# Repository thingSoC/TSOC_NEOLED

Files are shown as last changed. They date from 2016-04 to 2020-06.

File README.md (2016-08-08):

# TSOC_NEOLED

**TSOC_NEOLED** is a Eight-Channel WS2812 LED driver expansion board, and can drive
eight (8) to sixteen(16) strips of individually addressable Light Emitting Diodes (LEDs). 

**TSOC_NEOLED** uses a programmable system on chip (PSoC4) with an eight (8) channel driver
to drive hundreds of WS2812 Color LED's, with a default arrangement of 8 (eight strings) of sixty-four(64) LEDs each.

The **TSOC_NEOLED** can provide several different intefaces in order to make
interfacing large numbers of LEDs easy. The default protocol is an I2C interface :

1) I2C Serial DMX-512, Memory Mapped (**TSOC_NEOLED** looks like a 2048 byte I2C SRAM)

Other Interface protocols are possible (Firmware update using FTDI/USB-UART or JTAG) :

- UART Serial DMX-512 (200K Baud, N, 8, 1) with four DMX universes.

- SPI Serial DMX-512, Memory Mapped (**TSOC_NEOLED** looks like a 2048 byte SPI SRAM)

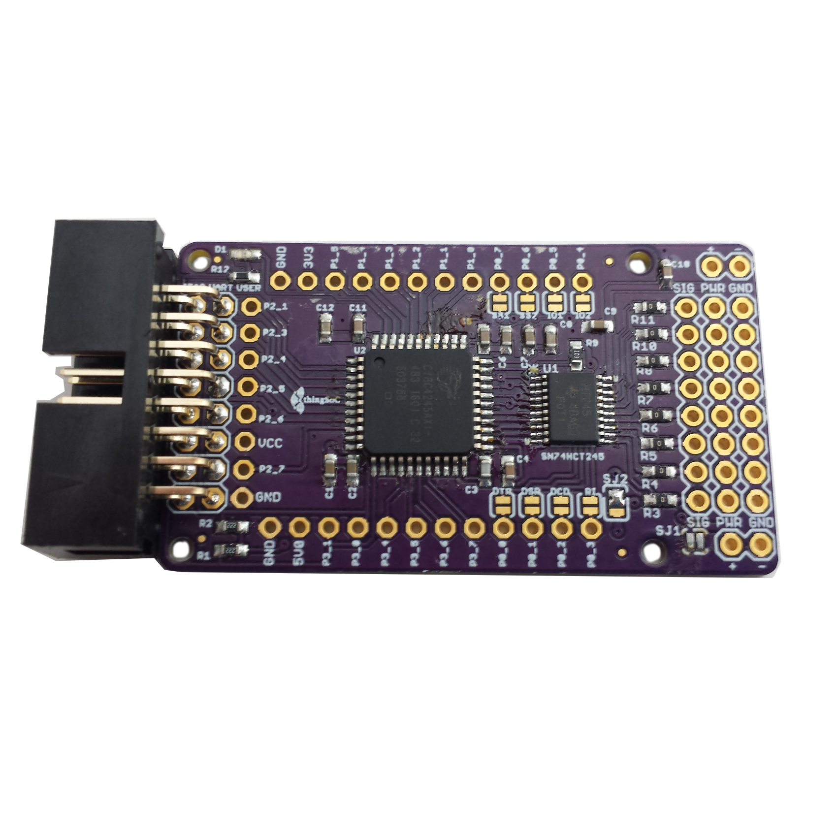
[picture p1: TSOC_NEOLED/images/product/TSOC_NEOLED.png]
thingSoC TSOC_NEOLED
[TSOC_NEOLED](https://github.com/thingSoC/TSOC_NEOLED)

**thingSoC Reference Designs** are example thingSoC implementations that implement
various reference and testing circuits for demonstrating the use of the thingSoC libraries.
These reference designs can serve as starting templates for user designs.

---------------------------------------

## TSOC_NEOLED Application Pictures

Using the TSOC_NEOLED to drive eight(8) strings of color LEDs for lighting our tandem bike for Portland PedalPolooza 2016

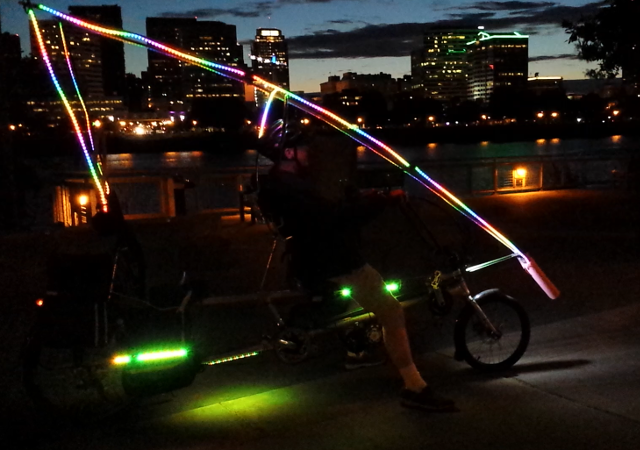
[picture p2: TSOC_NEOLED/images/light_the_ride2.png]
thingSoC TSOC_NEOLED
[*TSOC_NEOLED*](https://github.com/thingSoC/TSOC_NEOLED)

---------------------------------------

## TSOC_NEOLED Arduino Sketch Examples

Under the "examples" directory are several Arduino IDE examples for using the TSOC_NEOLED board with Arduino IDE.
Using the Arduino "Wire" library for I2C communications, it is simple to control the TSOC_NEOLED

```c
  // Start the Arduino I2C Interface
  wire.begin();

  // Turn the first LED On (i.e. green LED #1) 
  // the LED's are (GRBY) color order in memory
  byte row, column = 0;
  Wire.beginTransmission(TSOC_NEOLED_I2CADDRESS);  // Start the I2C transaction
  Wire.write(row);                                 // Send the high byte of 16 bit memory address
  Wire.write(column);                              // Send the low byte of 16 bit memory address
  Wire.write(TSOC_NEOLED_LED_ON);                  // Send a single data byte  (we could send more...)
  Wire.endTransmission();                          // End the I2C transaction
 
  // Turn the first LED Off (i.e. green LED #1) 
  // the LED's are (GRBY) color order in memory
  Wire.beginTransmission(TSOC_NEOLED_I2CADDRESS);  // Start the I2C transaction
  Wire.write(row);                                 // Send the high byte of 16 bit memory address
  Wire.write(column);                              // Send the low byte of 16 bit memory address
  Wire.write(TSOC_NEOLED_LED_OFF);                  // Send a single data byte  (we could send more...)
  Wire.endTransmission();                          // End the I2C transaction

```

---------------------------------------
## TSOC_NEOLED Programming

You can reprogram the board using any FTDI compatible USB to UART adapter :

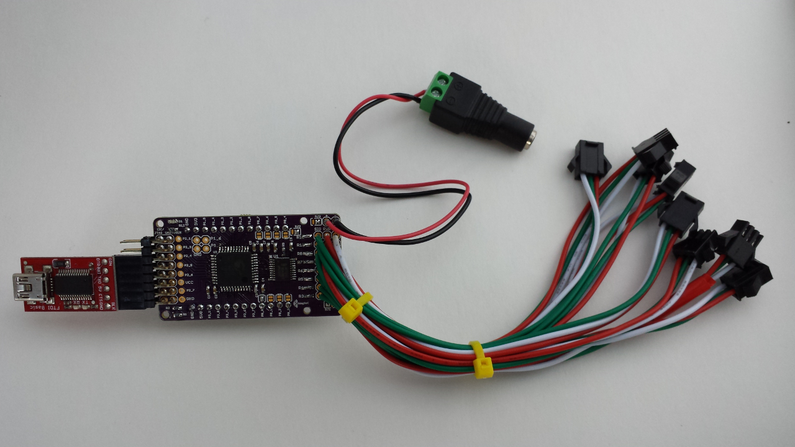
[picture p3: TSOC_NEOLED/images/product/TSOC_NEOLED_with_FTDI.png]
thingSoC TSOC_NEOLED
[TSOC_NEOLED with FTDI basic](https://github.com/thingSoC/TSOC_NEOLED)

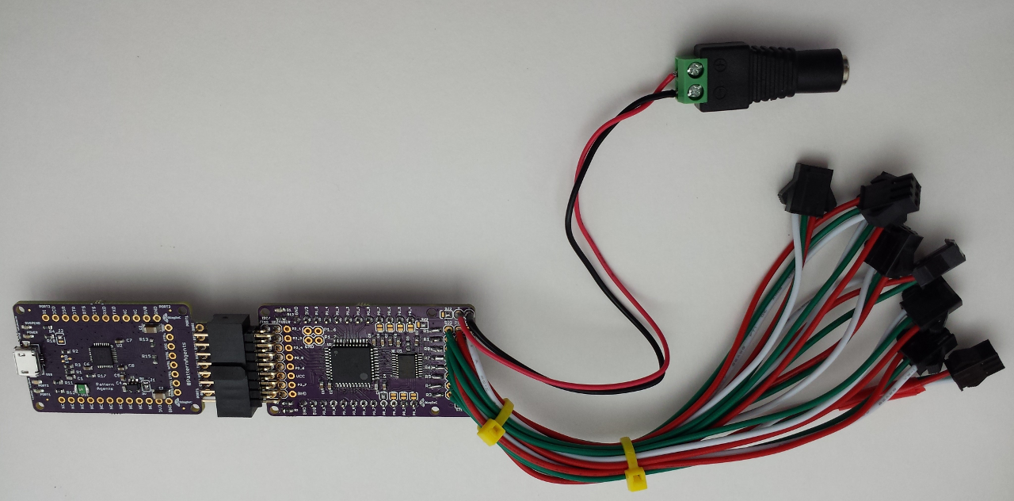
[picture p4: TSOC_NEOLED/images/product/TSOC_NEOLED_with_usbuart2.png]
thingSoC TSOC_NEOLED
[TSOC_NEOLED with TSOC_USBUART2](https://github.com/thingSoC/TSOC_NEOLED)

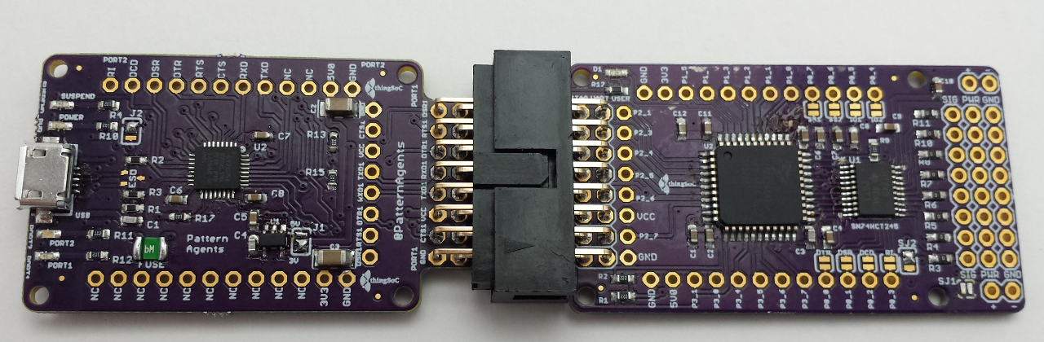
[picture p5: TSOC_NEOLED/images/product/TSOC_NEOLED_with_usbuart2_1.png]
thingSoC TSOC_NEOLED
[TSOC_NEOLED with TSOC_USBUART2](https://github.com/thingSoC/TSOC_NEOLED)

In order to reprogram the Cypress PSoC4 device, you will need to download and install the PSoC Creator tool, which includes a serial bootloader host application.

Select Tools -> Bootloader Host 

Then select the hex (cyacd) file that you wish to program, and the COM: port of your device. Proess the "Upload" button to reflash teh device.

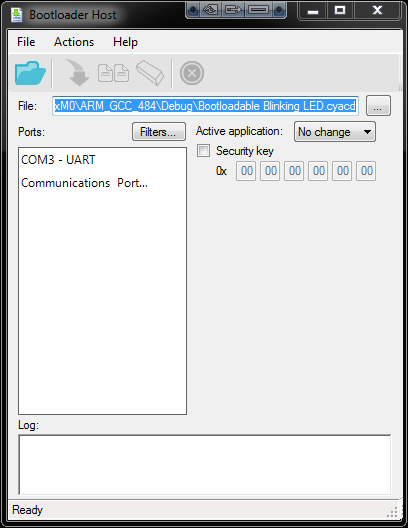
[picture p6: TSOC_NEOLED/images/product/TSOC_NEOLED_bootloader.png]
thingSoC TSOC_NEOLED
[PSoC Creator Bootloader Host](https://github.com/thingSoC/TSOC_NEOLED)

---------------------------------------
## Other Applications

The TSOC_NEOLED can also drive other devices, such as Servos, Motors, Realys and more.
This requires custom firmware at the current time.

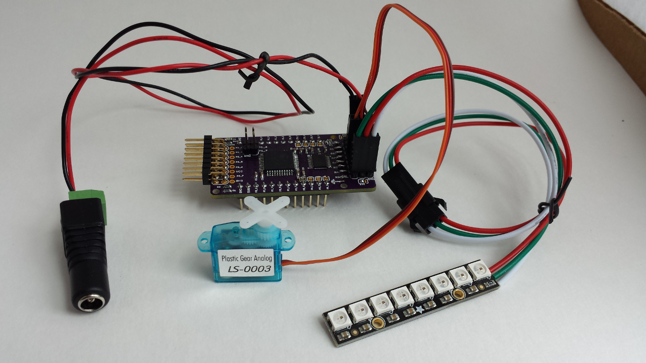
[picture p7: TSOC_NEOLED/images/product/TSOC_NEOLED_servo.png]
thingSoC TSOC_NEOLED
[TSOC_NEOLED with Servo](https://github.com/thingSoC/TSOC_NEOLED)

---------------------------------------

## TSOC_NEOLED Status <a name="TSOC_NEOLED_status"/>

**04/28/2016:** 
Revision 1.1 - Initial Layout with Eight(8) channel driver.

**06/27/2016:**
Revision 1.2 - Added extra power connections for higher current support.

**07/26/2016:**
Revision 2.0 -

               Moved extra jumpers to the Digital Programming Connector (i.e. boot-mode control).

               Added SAR Bypass capactitors in their place.  
               
               Misc Silkscreen clean up.  
               
               Add Fiducials and DFM cleanup.

---------------------------------------
## TSOC_NEOLED Model Images

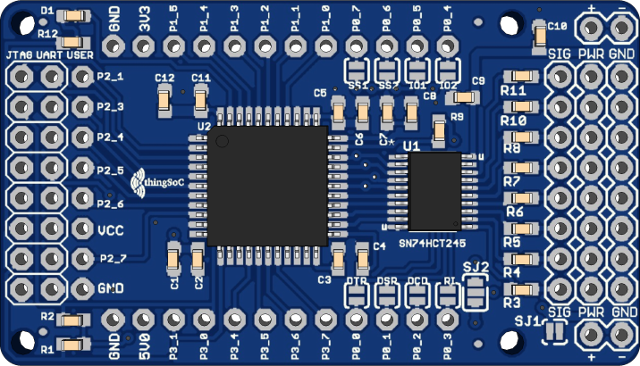
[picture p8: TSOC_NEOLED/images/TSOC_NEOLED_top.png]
thingSoC TSOC_NEOLED
[TSOC_NEOLED](https://github.com/thingSoC/TSOC_NEOLED)

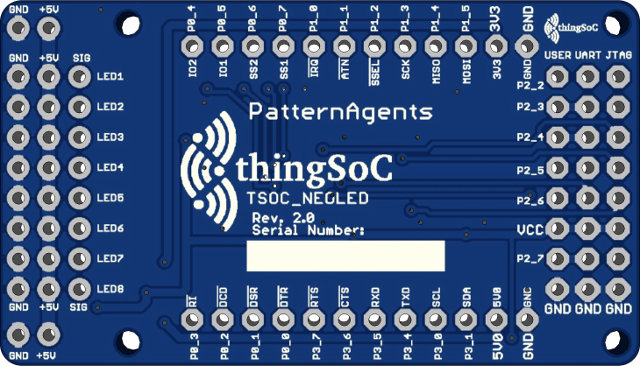
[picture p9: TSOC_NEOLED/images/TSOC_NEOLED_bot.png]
thingSoC TSOC_NEOLED
[TSOC_NEOLED](https://github.com/thingSoC/TSOC_NEOLED)

---------------------------------------

## TSOC_NEOLED Documentation Index <a name="TSOC_NEOLED_documentation_index"/>

[TSOC_NEOLED Project](http://thingsoc.github.io/projects/TSOC_NEOLED.html)

[TSOC_NEOLED Hardware](https://github.com/thingSoC/TSOC_NEOLED/tree/master/TSOC_NEOLED/hardware)

---------------------------------------

## thingSoC Documentation Index <a name="thingSoC_documentation_index"/>

[thingSoC Organization Website](http://thingSoC.github.io)

[thingSoC FAQ - Frequently Asked Questions](http://thingsoc.github.io/support/faq.html)

---------------------------------------

[thingSoC 
*thingSoC*](http://thingsoc.github.io)

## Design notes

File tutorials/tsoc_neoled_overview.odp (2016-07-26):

## thingSoC

  NEOLED Overview:  An Introduction to WS2812 LEDs

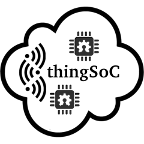
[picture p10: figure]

By
@PatternAgents

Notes: Hey Everybody! I’m Tom Moxon, and I’m very pleased to be speaking with you today- I see some new faces in the audience as well as some old friends – welcome !

## Addressable LEDs

- WS2810/WS2812 (a.k.a. NEOPixels by Adafruit) Integrates an LED driver chip with Red, Green, Blue LED's

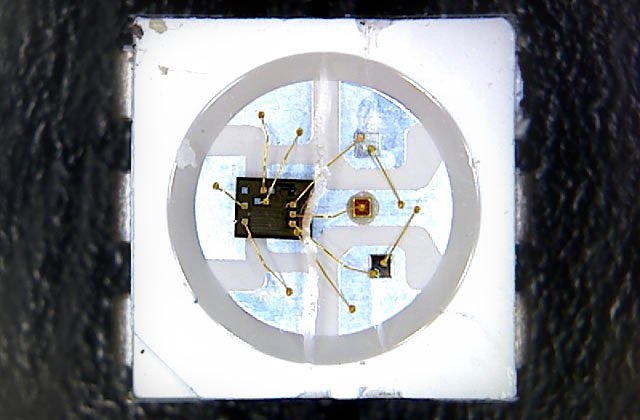
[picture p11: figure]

## WS2812 (SK6812) Color LEDs

- Likely the most common addressable LED you'll find (called NEOPixels when you buy them at Adafruit!)
- They use a serial bit stream (UART like) protocol that can be difficult for some microcontrollers or Linux single board computers (SBC) to drive directly (tight timing...)
- It can also be difficult to drive and synchronize hundreds of WS2812 LEDs in multiple strings without hardware acceleration of some kind (special circuit, DMA, etc.)
  Source : @PatternAgents

## WS2812 Wiring

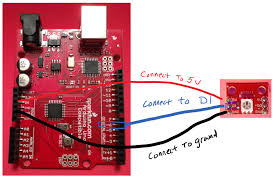
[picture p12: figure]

- Needs 5.0 Volt Power
- Needs 5.0 Volt Signal
- Can draw AMPS of Power with many LEDs
- Do NOT do this with more than a few LEDs, it can fry your Arduino boards...

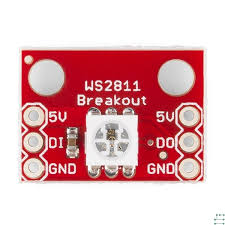
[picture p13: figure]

  Source : Sparkfun

## WS2812 Wiring

- Best Practice is to power the LED strings separately:

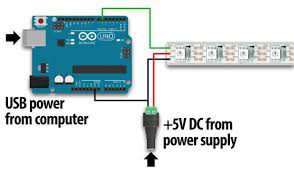
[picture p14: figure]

## WS2812 Timing

- The older WS2810 was a 400KHz serial data signal
- The newer WS2811/WS2812 are now 800KHz data signals

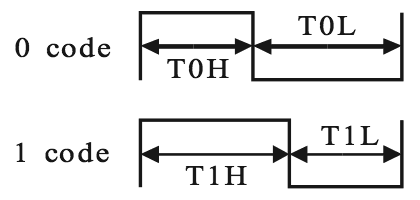
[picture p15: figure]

  Source : Adafruit

## WS2812 LED Color Order

- Eight (8) bits each for Green, Red, Blue
- Different chips can use different color orders (beware!)
- Some add White or Yellow LEDs for a 32 bit color pixel
  Source : Adafruit

## Arduino Libraries

- Adafruit NeoPixel Library : Well written, supports AVR, ESP8266, SAMD, etc.
- FastLeds Library : Optimized, with higher performance and update rates
- Problems : 1) Can interfere with other functions, like audio, servos, etc. 2) Can use up a lot of the “scarce” memory resource 3) Doesn't work well with the Edison, Currie, Galileo, etc.
  Source : Adafruit

## thingSoC is a OSHW Standard

Growing into a family of inter-operable products:

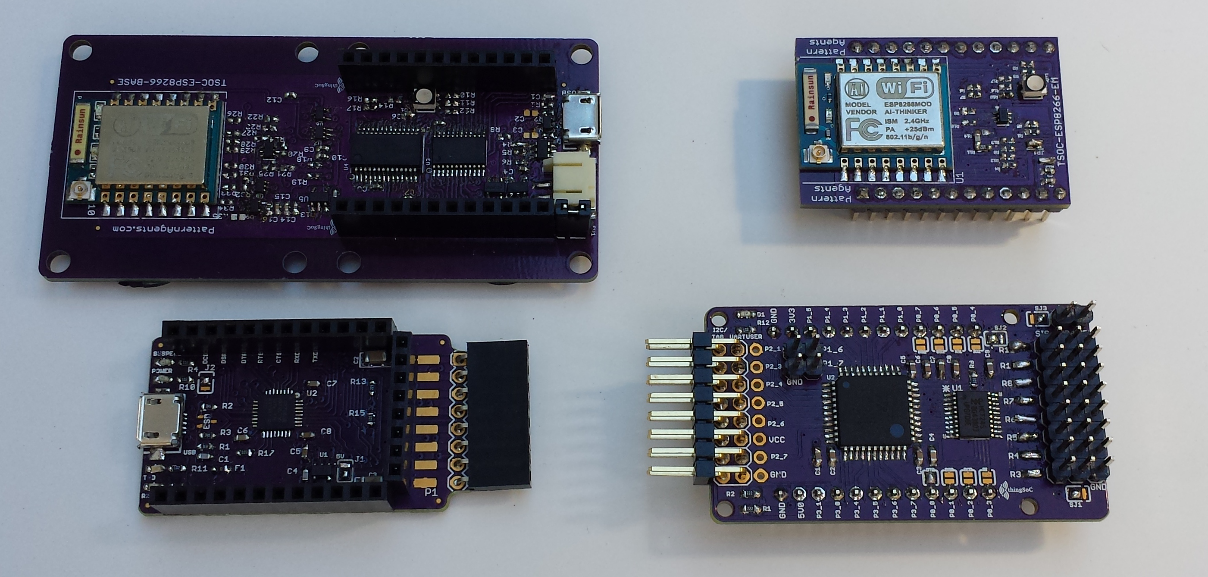
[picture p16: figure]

  source: @PatternAgents

## TSOC_NEOLED_EM

- Eight (8) Channel RBG(Y) LED Driver Board (Embeddable Module) Makes driving LED arrays as easy as writing to an I2C memory
- Reprogrammable for other functions (servo motors, etc.)
- Works with other thingSoC products
- Coming soon to Crowd Supply here in Portland!

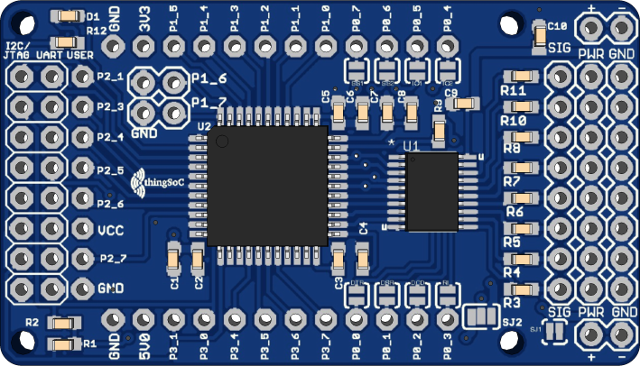
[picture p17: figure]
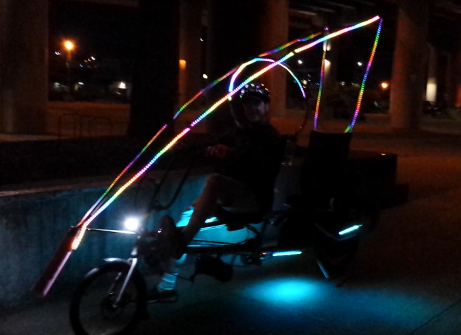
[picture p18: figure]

  Source : @PatternAgents

## Driving WS2812 with Edison

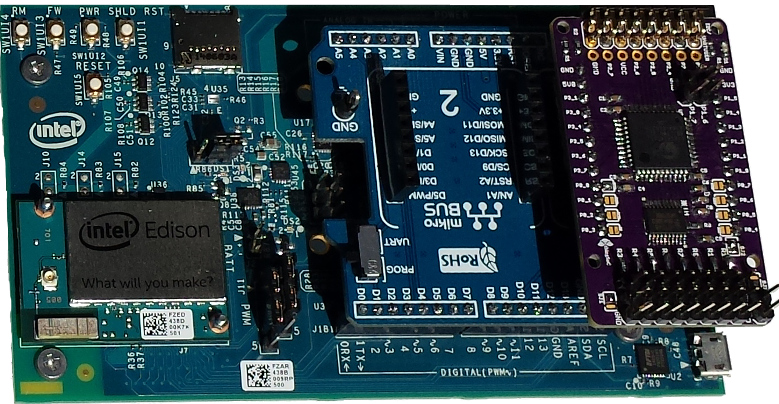
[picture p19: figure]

  source: @PatternAgents

## Driving WS2812 with Edison

- While there are ways to drive WS2812 LEDs directly from the Edison (MRAA), they are not easy and have other problems.
- Using the TSOC_NEOLED board eliminates the timing and voltage level translation issues for you.
- The TSOC_NEOLED board looks like a simple I2C memory device to the Edison, simplifying your code.

Driving WS2812 with Edison

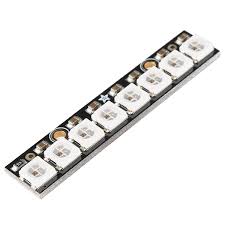
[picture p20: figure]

  source: @PatternAgents

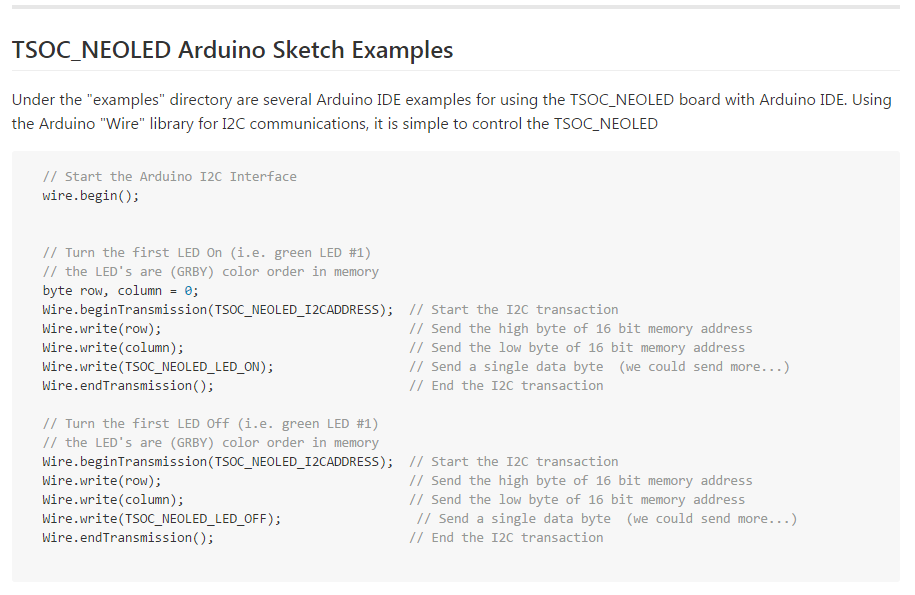
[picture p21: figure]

  source: @PatternAgents

## Hackster.io Platform

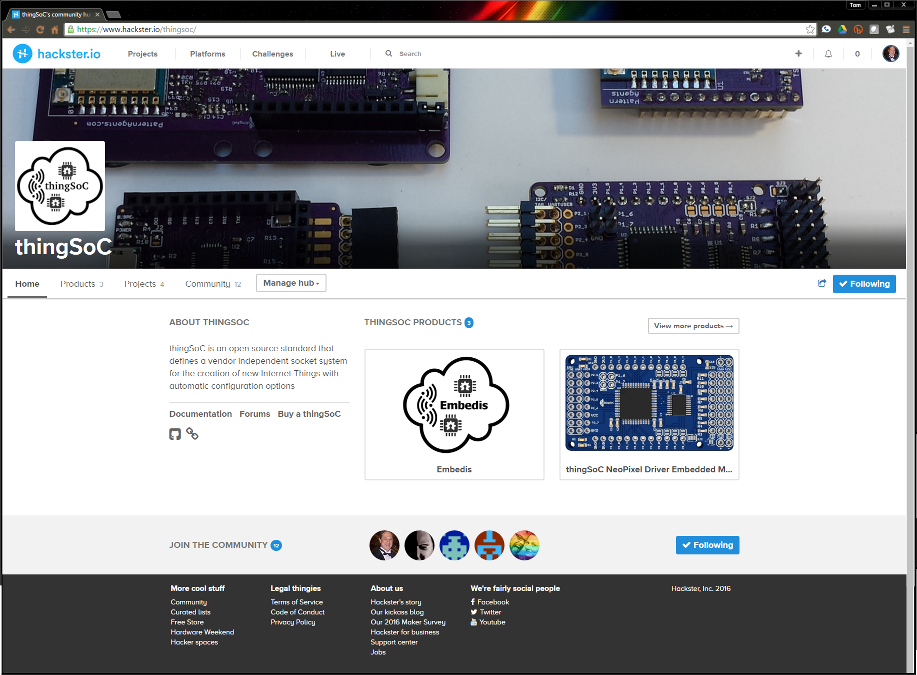
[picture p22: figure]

  source: PatternAgents

## Hackster.io Projects

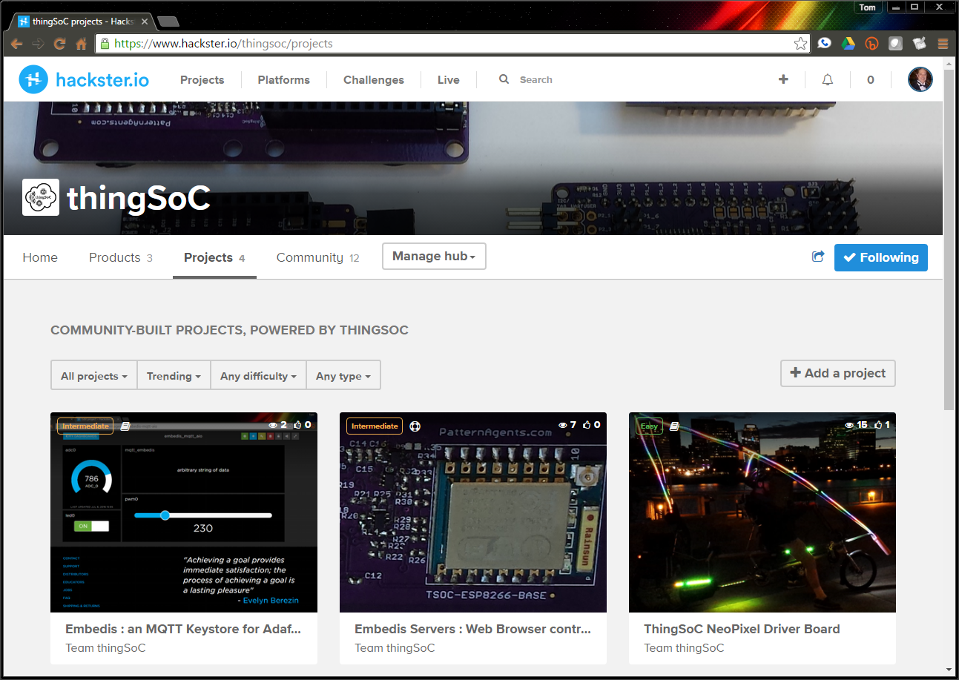
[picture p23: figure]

  source: PatternAgents

## If you would like to help...

- Sign Up for Hackster.IO
- Please go to : https://www.hackster.io/thingsoc and “Click” on the blue “Following” button
- Look for our Crowd Supply campaign coming soon!

## Thank You !

  Thank You!
  Source : @PatternAgents

## @Pattern Agents

- PatternAgents supplies Open Source Design Patterns for Hardware, Firmware, Software, and Applications.
- A tailor or dressmaker is very familiar with the concept of a "pattern"; they select a “pattern” for the style of garment that they want to make, and then size that “pattern” for the customers individual measurements.
- PatternAgents is doing the same thing for electronics, in embedded systems for communications, robotics, metering and automation.

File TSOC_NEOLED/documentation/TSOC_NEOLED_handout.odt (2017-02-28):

thingSoC NEOLED Board

Thank you for purchasing a TSOC_NEOLED board!
Please see the Getting Started Guide at :
https://github.com/thingSoC/TSOC_NEOLED
It has complete instructions and examples to download.

thingSoC NEOLED Board

Thank you for purchasing a TSOC_NEOLED board!
Please see the Getting Started Guide at :
https://github.com/thingSoC/TSOC_NEOLED
It has complete instructions and examples to download.

thingSoC NEOLED Board

Thank you for purchasing a TSOC_NEOLED board!
Please see the Getting Started Guide at :
https://github.com/thingSoC/TSOC_NEOLED
It has complete instructions and examples to download.

thingSoC NEOLED Board

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

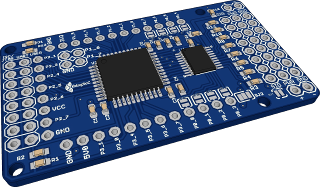
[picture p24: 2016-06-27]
TSOC_NEOLED/images/rev2.0/TSOC_NEOLED_model.png

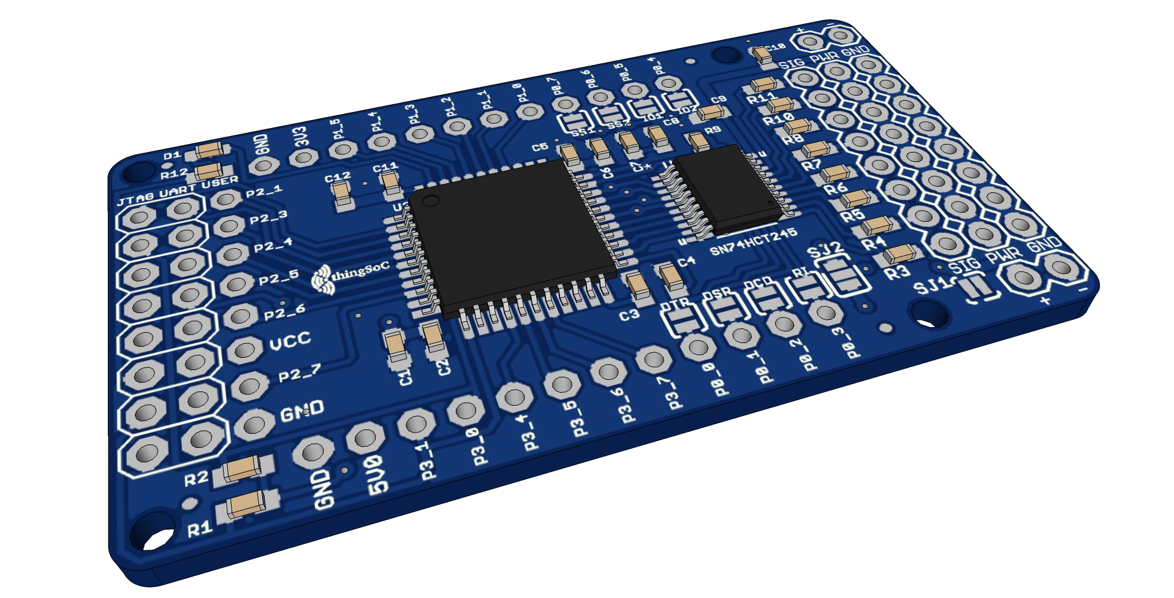
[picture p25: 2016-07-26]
TSOC_NEOLED/images/rev2.0/TSOC_NEOLED_iso.png

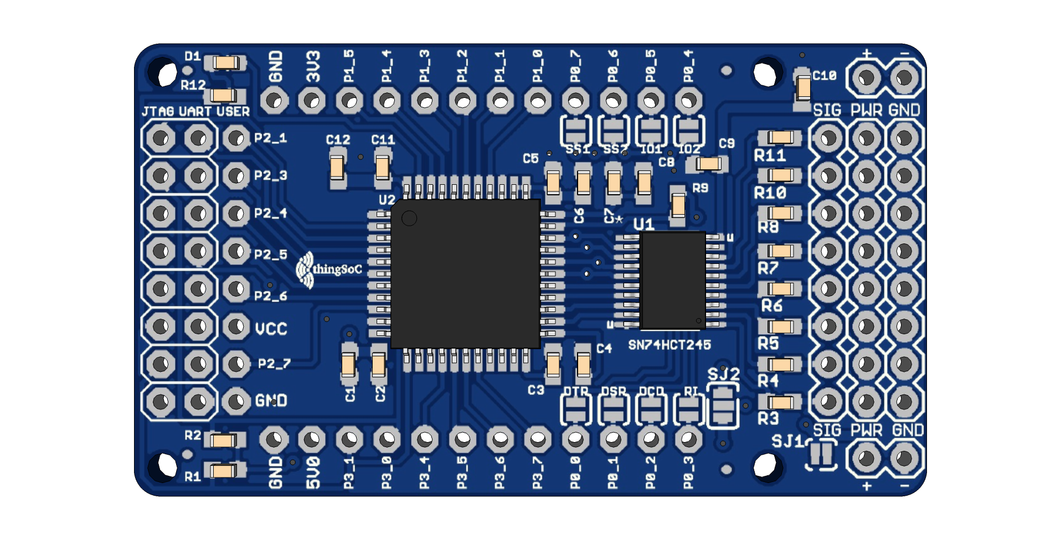
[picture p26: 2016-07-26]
TSOC_NEOLED/images/rev2.0/TSOC_NEOLED_top.png

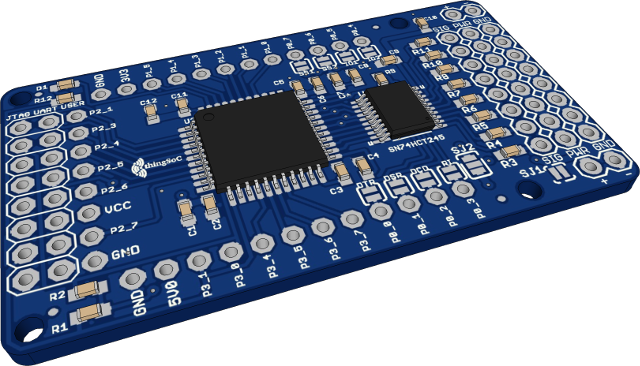
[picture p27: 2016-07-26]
TSOC_NEOLED/images/TSOC_NEOLED_iso.png

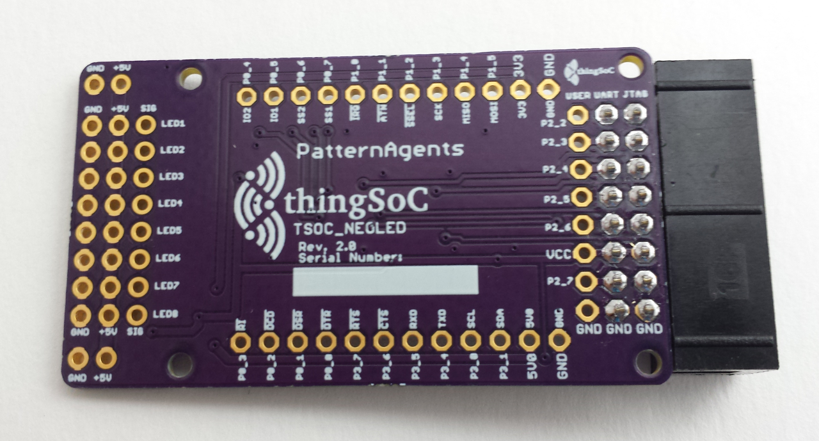
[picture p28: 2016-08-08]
TSOC_NEOLED/images/product/TSOC_NEOLED_bot.png

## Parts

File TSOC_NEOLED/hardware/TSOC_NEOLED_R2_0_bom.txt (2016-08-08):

Partlist exported from U:/PatternAgents/eagle/TSOC_Modules/TSOC_NEOLED/TSOC_NEOLED/TSOC_NEOLED.sch at 7/26/2016 10:40:16 PM
Revison 2.0
------------
Part  Value           Device               Package           Description                      DIGIKEY               MPN 
C1    0.1uF           CAP0603-CAP          0603-CAP          Capacitor                     490-1524-2-ND          muRata GRM188R71E104KA01D  
C2    1uF             CAP0603-CAP          0603-CAP          Capacitor                                            muRata GRM185R61C105K                                                                        
C3    2.2nF           CAP0603-CAP          0603-CAP          Capacitor                                            muRata GRM188R61C225K                                                                        
C4    10nF            CAP0603-CAP          0603-CAP          Capacitor                     490-4778-1-ND          muRata GCM188R71H103KA37D                                                                                          
C5    0.1uF           CAP0603-CAP          0603-CAP          Capacitor                                                                                                                          
C6    1uF             CAP0603-CAP          0603-CAP          Capacitor                                                                                                                          
C7    0.1uF           CAP0603-CAP          0603-CAP          Capacitor                                                                                                                          
C8    1uF             CAP0603-CAP          0603-CAP          Capacitor                                                                                                                          
C9    0.1uF           CAP0603-CAP          0603-CAP          Capacitor                                                                                                                          
C10   0.1uF           CAP0603-CAP          0603-CAP          Capacitor                                                                                                                          
C11   0.1uF           CAP0603-CAP          0603-CAP          Capacitor                                                                                                                          
C12   1uF             CAP0603-CAP          0603-CAP          Capacitor                                                                                                                          
D1    RED             LED0603              LED-0603          LEDs                             475-2506-1-ND        OSRAM   LS L29K-G1J2-1-Z                                                                                          
J1    M08X02          M08X2                2X8               .1" headers, Male, Shrouded, RA  ED10535-ND           On-Shore-Technology-Inc. 302-R161                                                                                            
J2    M08             M08                  1X08              .1" headers, Male, Unshrouded,   S1012EC-08-ND        Sullins  PREC008SAAN-RC                                                                                                                       
J3    M08             M08                  1X08              .1" headers, Male, Unshrouded,   S1012EC-08-ND        Sullins  PREC008SAAN-RC                                                                                                                        
J4    M08             M08                  1X08              .1" headers, Male, Unshrouded,   S1012EC-08-ND        Sullins  PREC008SAAN-RC
J5    M02             M02                  1X02              .1" headers, Male, Unshrouded                                                                                      
J6    M02             M02                  1X02              .1" headers, Male, Unshrouded                                                                           
R1    2K2             RESISTOR0603-RES     0603-RES          Resistor                         RMCF0603JT2K20TR-ND   Stackpole RMCF0603JT2K20                                                                                                  
R2    2K2             RESISTOR0603-RES     0603-RES          Resistor                                                                                                                           
R3    0               RESISTOR0603-RES     0603-RES          Resistor                                                                                                                           
R4    0               RESISTOR0603-RES     0603-RES          Resistor                                                                                                                           
R5    0               RESISTOR0603-RES     0603-RES          Resistor                                                                                                                           
R6    0               RESISTOR0603-RES     0603-RES          Resistor                                                                                                                           
R7    0               RESISTOR0603-RES     0603-RES          Resistor                                                                                                                           
R8    0               RESISTOR0603-RES     0603-RES          Resistor                                                                                                                        
R9    10K             RESISTOR0603-RES     0603-RES          Resistor                         RMCF0603JT10K0TR-ND   Stackpole RMCF0603JT10K0                                                                                           
R10   0               RESISTOR0603-RES     0603-RES          Resistor                                                                                                                           
R11   0               RESISTOR0603-RES     0603-RES          Resistor                                                                                                                           
R12   1K              RESISTOR0603-RES     0603-RES          Resistor                         RMCF0603JT1K00TR-ND   Stackpole RMCF0603JT1K00                                                                                                                                                             
TSOC1 M12             M12                  1X12F             .1" headers, Female              S6100-ND               PPTC121LFBN-RC
TSOC2 M12             M12                  1X12F             .1" headers, Female              S6100-ND               PPTC121LFBN-RC
TSOC3 M08             M08                  1X08F             .1" headers, Female              S7006-ND               PPTC081LFBN-RC                                                                                               
U1    SN74HCT245PWR    SN74HCT245PWR       SOP65P640X120-20N OCTAL BUS TRANS                  296-8404-1-ND          SN74HCT245PWR
U2    CY8C42XX-44PIN  CY8C42XX-44PIN       TQFP-10X10-44     Cypress PSoC® 4                  CY8C4245AXI-483

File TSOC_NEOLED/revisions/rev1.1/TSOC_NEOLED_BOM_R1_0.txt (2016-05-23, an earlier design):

Partlist exported from /home/moxon/github/TSOC_NEOLED/TSOC_NEOLED/TSOC_NEOLED.sch at 4/29/16 10:46 AM
Qty Value           Device               Package           Parts                                 Description                                                     
8                   JMP-2-NO             JMP-2-NO          DCD, DSR, DTR, IO1, IO2, RI, SS1, SS2 Two Terminal Jumper - Normally Open 
1                   LED0603              LED-0603          D1                                    LEDs                                                            
3                   M08                  1X08_ROUND        J2, J3, J4                            Header 8                                                        
1                   M08X2                2X8               J1                                    .1" headers, two rows of 8 each                                 
8                   RESISTOR0603-RES     0603-RES          R3, R4, R5, R6, R7, R8, R10, R11      Resistor                                                        
4   0.1uF           CAP0603-CAP          0603-CAP          C1, C5, C7, C9                        Capacitor                                                       
1   10K             RESISTOR_SFE0603-RES 0603-RES          R9                                    Resistor                                                        
1   10nF            CAP0603-CAP          0603-CAP          C4                                    Capacitor                                                       
1   1K              RESISTOR_SFE0603-RES 0603-RES          R12                                   Resistor                                                        
3   1uF             CAP0603-CAP          0603-CAP          C2, C6, C8                            Capacitor                                                       
1   2.2nF           CAP0603-CAP          0603-CAP          C3                                    Capacitor                                                       
2   2K2             RESISTOR_SFE0603-RES 0603-RES          R1, R2                                Resistor                                                        
1   CY8C42XX-44PIN  CY8C42XX-44PIN       TQFP-10X10-44     U2                                    Cypress PSoC® 4 - Programmable System on Chip
3   JMP-3-1_2       JMP-3-1_2            JMP-3-1_2         SJ1, SJ2, SJ3                         Three Terminal Jumper - 1 & 2 Connected                         
3   M02             M02                  1X02              5V, SP1, SP2                          
1   SN74HC245PW     SN74HC245PW          SOP65P640X120-20N U1                                    OCTAL BUS TRANSCEIVERS

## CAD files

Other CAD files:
TSOC_NEOLED/eagleUp/TSOC_NEOLED.skp

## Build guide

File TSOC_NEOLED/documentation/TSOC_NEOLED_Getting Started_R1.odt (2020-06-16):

Welcome to the thingSoC® NEOLED

The TSOC_NEOLED is a PSoC4-Programmable System on Chip (http://www.cypress.com/file/138656/download) based board with an integrated eight (8) channel driver for WS2812 type color LED's, in an Embedded Module format for the new thingSoC, Internet of Things open source hardware standard.


CAUTION !

Large strings of WS2812 LEDs can require several AMPS of power, make sure to use a suitable five (5.0) Volt power supply when powering your strings of lights at full brightness !

The TSOC_NEOLED is a very flexible board, but care should be taken to configure the power straps and connectors properly to avoid damage to your board(s)!

Default Jumper Settings :

SJ1 : OPEN : WS2812 LED strings require an external 5V power supply connected to PWR/GND pins
SJ2 : 3.3V : The PsoC4 device is powered from the thingSoC 3.3V rails for 3.3V operation
I2C Operation : The TSOC_NEOLED is an I2C peripheral at I2C address 0X08 and 100Khz bus speed

TSOC_NEOLED Operating Modes :

The TSOC_NEOLED has three (3) different operating modes, namely :

1. Normal Operation Mode (default) – in normal operating mode the TSOC_NEOLED listens to the I2C (Two-Wire Interface) on pins P3_0, and P3_1, at I2C address 0X08 and 100Khz bus speed. Normal operating mode is indicated by the onboard LED being solidly illuminated. In normal operating mode, no LED's will light up until you send an I2C command to the TSOC_NEOLED at I2C slave address 0X08. The TSOC_NEOLED looks like an I2C Memory device, and writing to a memory location causes that LED to light.  The address mapping is : 0 – String 0, LED0, Green 1 – String 0, LED0, Red 2 – String 0, LED0, Blue 3 – String 0, LED0, Yellow/White (ignored if only RGB LEDs...) 4 – String 0, LED1, Green 5 – String 0, LED1, Red 6 – String 0, LED1, Blue 7 – String 0, LED1, Yellow/White (ignored if only RGB LEDs...) ... 64 – String 1, LED0, Green 65 – String 1, LED0, Red 66 – String 1, LED0, Blue 67 – String 1, LED0, Yellow/White (ignored if only RGB LEDs...) .... etc.
2. Demo Mode – demo mode is selected by connecting pin P1_7 to GROUND for ten (10) seconds. In Demo Mode, a number of different pre-programmed LED patterns can be selected using pin P1_6. "Touch" pin P1_6 to GROUND briefly to select the different LED patterns. Once you cycle though all the LED patterns, the device returns to normal operation mode. Demo mode is indicated by a very slow blinking of the onboard LED.
3. Bootloader Mode - Bootloader Mode is selected by by connecting pin P1_6 to GROUND for ten (10) seconds. Bootloader Mode is used to update the onboard firmware using a standard "FTDI" type USB to UART adaptor board (sold separately). Bootloader Mode is indicated by a very fast blinking of the onboard LED.

Assembling and Configuring the TSOC_NEOLED Board :

For maximum flexability, the TSOC_NEOLED board comes from the factory unconfigured, and can be assembled in a number of different configurations, such as 3.3V/5.0V operation and Internal/External Power Selection. The board comes with only a reprogramming connector attached, so that you can update the firmware if desired.

SJ1 : OPEN :
WS2812 LED strings require an external 5V power supply connected to PWR/GND pins.

SJ1 : CLOSED :
WS2812 LED strings connect to onboard VCC directly. This is only recommended for standalone operation where the TSOC_NEOLED will be used without any other 3.3 Volt thingSoC boards attached, or where only 5.0V Mikrobus boards will be used. If SJ1 is closed, also move SJ2 to the 5.0Volt position to provide 5.0V power to any attached Mikrobus boards.

SJ2 : 3.3V (RIGHT) :
The PsoC4 device is powered from the thingSoC 3.3V rails for 3.3V operation.

SJ2 : 5.0V (LEFT) :
The PsoC4 device is powered from the thingSoC 5.0V rails for 5.0V operation.
Caution : Attaching a 3.3V board in this configuration will likely cause damage to the attached board.

Optional Jumpers :
Pins P0_0 through P0_7 are normally connected to the LED driver chip, and are not connected to the thingSoC connectors. If you are not using all eight (8) strings, then some of those signals can bu reused, if needed. These eight(8) jumpers are open by default.

Safe Handling Precautions :

1) Always remove/unplug all power before inserting or removing peripherals.
2) Always ground yourself by touching a ground point before handling your boards.
3) Use a static safe bag when transporting your TSOC_NEOLED board.

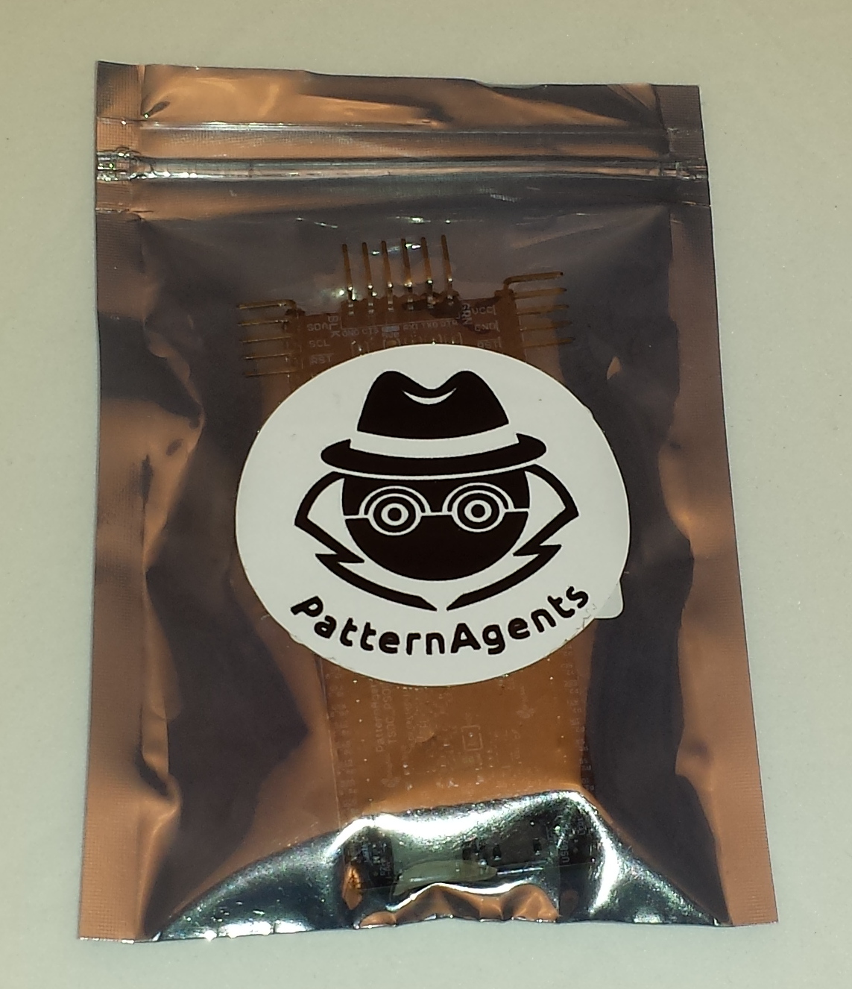
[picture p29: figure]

Adding Peripherals :
The TSOC_NEOLED board supports both thingSoC and Mikrobus peripherals.
1) Make sure to align the SQUARE/CUT edges of the boards together to insure that
the polarity is correct. Push down evenly to seat the boards in the socket.
2) Note that the "stacking pins" are somewhat longer by design, and there will be some
extra space between the boards when using stacking connectors.

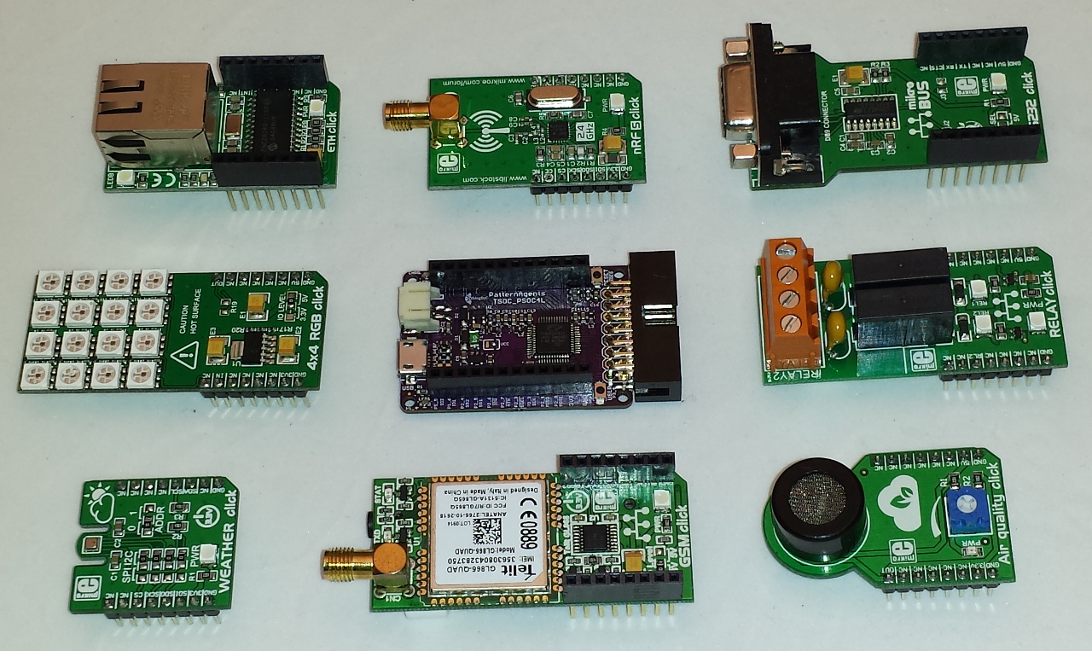
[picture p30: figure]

Other Uses and Configurations :


The TSOC_NEOLED board has been designed to be able to drive other peripherals as well as WS2812 programmable LEDs. The pinout of the eight (8) driver channels is also compatible with common stepper motors, and the board can drive up to eight (8) motors. A custom firmware load is required for other applications.

Reprogramming the TSOC_NEOLED Board :

The TSOC_NEOLED board comes pre-loaded with a UART bootloader, which executes
if you connect pin P1_6 to GROUND for (10) seconds after powering up the board.
You can use a standard "FTDI" type USB to UART adaptor to connect the TSOC_NEOLED
to your computer.


The TSOC_NEOLED board can be programmed using the Cypress PSoC Creator IDE,
which is a free download (registration required) from Cypress Semiconductor, and can be
found at :

http://www.cypress.com/products/psoc-creator-integrated-design-environment-ide

Cypress has a number of excellent videos and instructions online for using Creator.

The TSOC_NEOLED board can also be programmed using the Cypress PSoC Programmer tool.
The PSoC Programmer tool is a free download (registration required) from Cypress Semiconductor,
and can be found at :

http://www.cypress.com/documentation/software-and-drivers/psoc-programmer-3245 (http://www.cypress.com/documentation/software-and-drivers/psoc-programmer-3245)

Using the Cypress PsoC Creator "Bootloader Host" Program :

Included with the Cypress PsoC Creator IDE tool is a simple programming utility called the "Bootloader Host" program. Without any detailed knowledge of the PsoC Creator IDE, the "Bootloader Host" program can be used to simply update the firmware program in your TSOC_NEOLED device. Simply select the correct COM: port for your "FTDI" type USB-to-UART adaptor and a baud rate of 115200 Baud for reprogamming.

Connect Pin P1_6 to GROUND for ten (10) or more senconds, and the LED on the board will begin flashing quickly, indicating that the bootloader if running on your TSOC_NEOLED device.
Use the file icon to select a new *.cyacd firmware file for download, and then press the "Download" arrow to begin reprogramming your device – that's all there is to it. Now you new firmware has been installed into your TSOC_NEOLED device.


"Bare Metal" Programming :

At the factory we use a Cypress MiniProg3 JTAG programmer to install the default firmware on your TSOC_NEOLED board before it ships to you. If you would like to do bare metal programming or to use the PSoC Creator debugger, you will need a MiniProg3 and a MiniProg adapter.
You can find more information about the MiniProg3 here :
http://www.cypress.com/documentation/development-kitsboards/cy8ckit-002-psoc-miniprog3-program-and-debug-kit

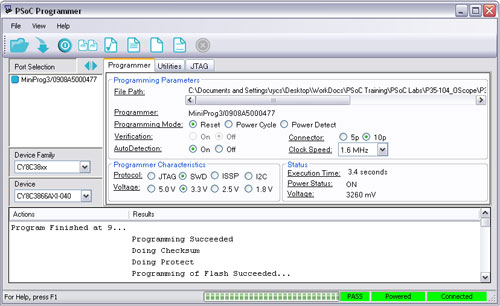
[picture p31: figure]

thingSoC MiniProg Adapter :

The thingSoC MiniProg adapter is used to provide several interfaces through a single common
connector on the TSOC_NEOLED board, including JTAG, UART, and I2C as shown :

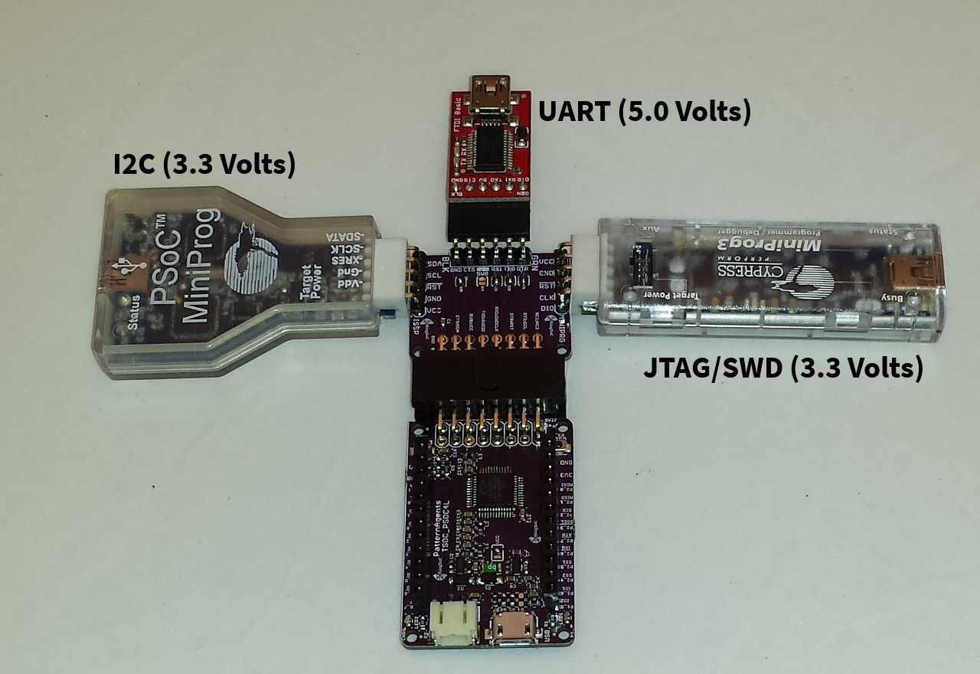
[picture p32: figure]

The thingSoC MiniProg adapter implements the thingSoC DPC (Digital Programming Connector) and allows for programming, testing, and debugging using either a UART or I2C bootloader, or bare metal programming using JTAG/SWD. This is generally for advanced users only, and is not normally required for User programming. Most Users wll simply use the USB interface for reprogramming.
Note that the USB-UART (FTDI) is a 5.0 Volt ONLY connection for backward compatibility.

thingSoC® NEOLED Features :

The TSOC_NEOLED is a low cost, embeddable module featuring a PSoC4 device :

- 32-bit MCU Subsystem (48MHZ ARM Cortex-M0)
- Programmable Digital Blocks (4 blocks)
- 3.3 Volt or 5.0 Volt Operation
- External or Bus Power Selection (External Power by default)
- Eight (8) Channel Driver
- I2C Two-Wire Bus Interface (100kHz , Address 0x08 by default)
- Serial Communication (8, N , 1, 115200 Baud by default)
- Counter/Timers/PWMs (4 Ports)
- USER LED
- thingSoC Compatible Module
- Mikrobus Compatible Module (http://www.mikroe.com/mikrobus/)

For Revison 1.2 NEOLED Boards

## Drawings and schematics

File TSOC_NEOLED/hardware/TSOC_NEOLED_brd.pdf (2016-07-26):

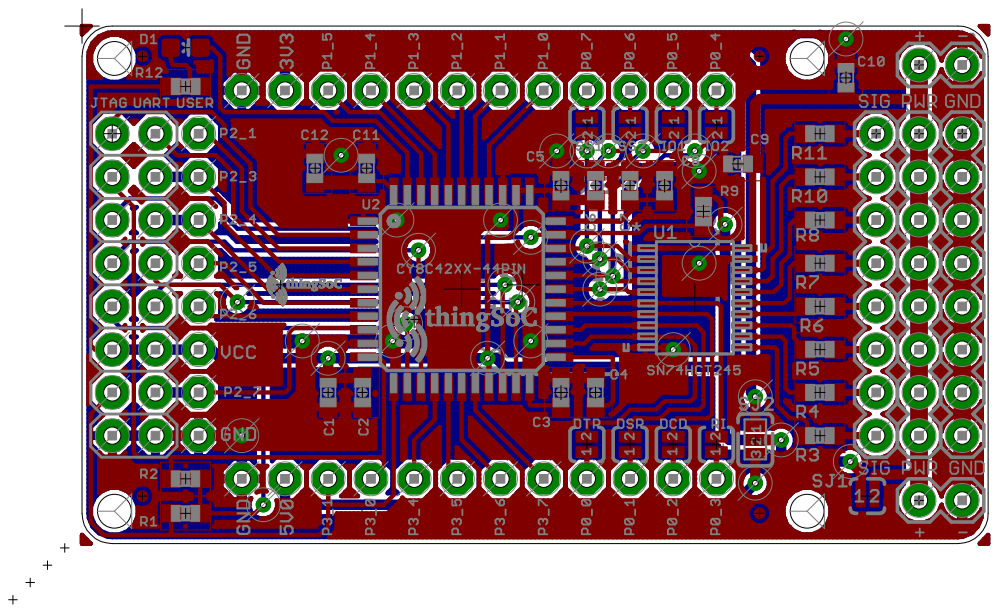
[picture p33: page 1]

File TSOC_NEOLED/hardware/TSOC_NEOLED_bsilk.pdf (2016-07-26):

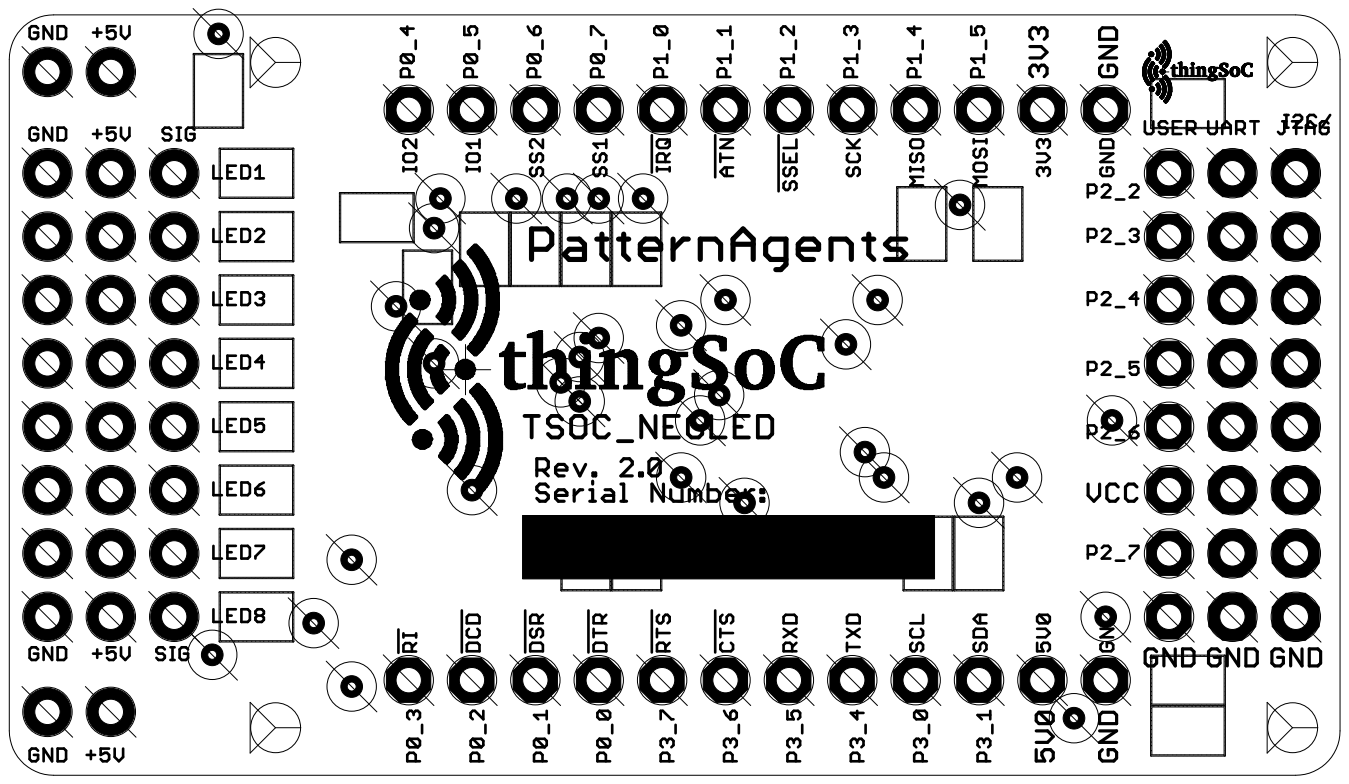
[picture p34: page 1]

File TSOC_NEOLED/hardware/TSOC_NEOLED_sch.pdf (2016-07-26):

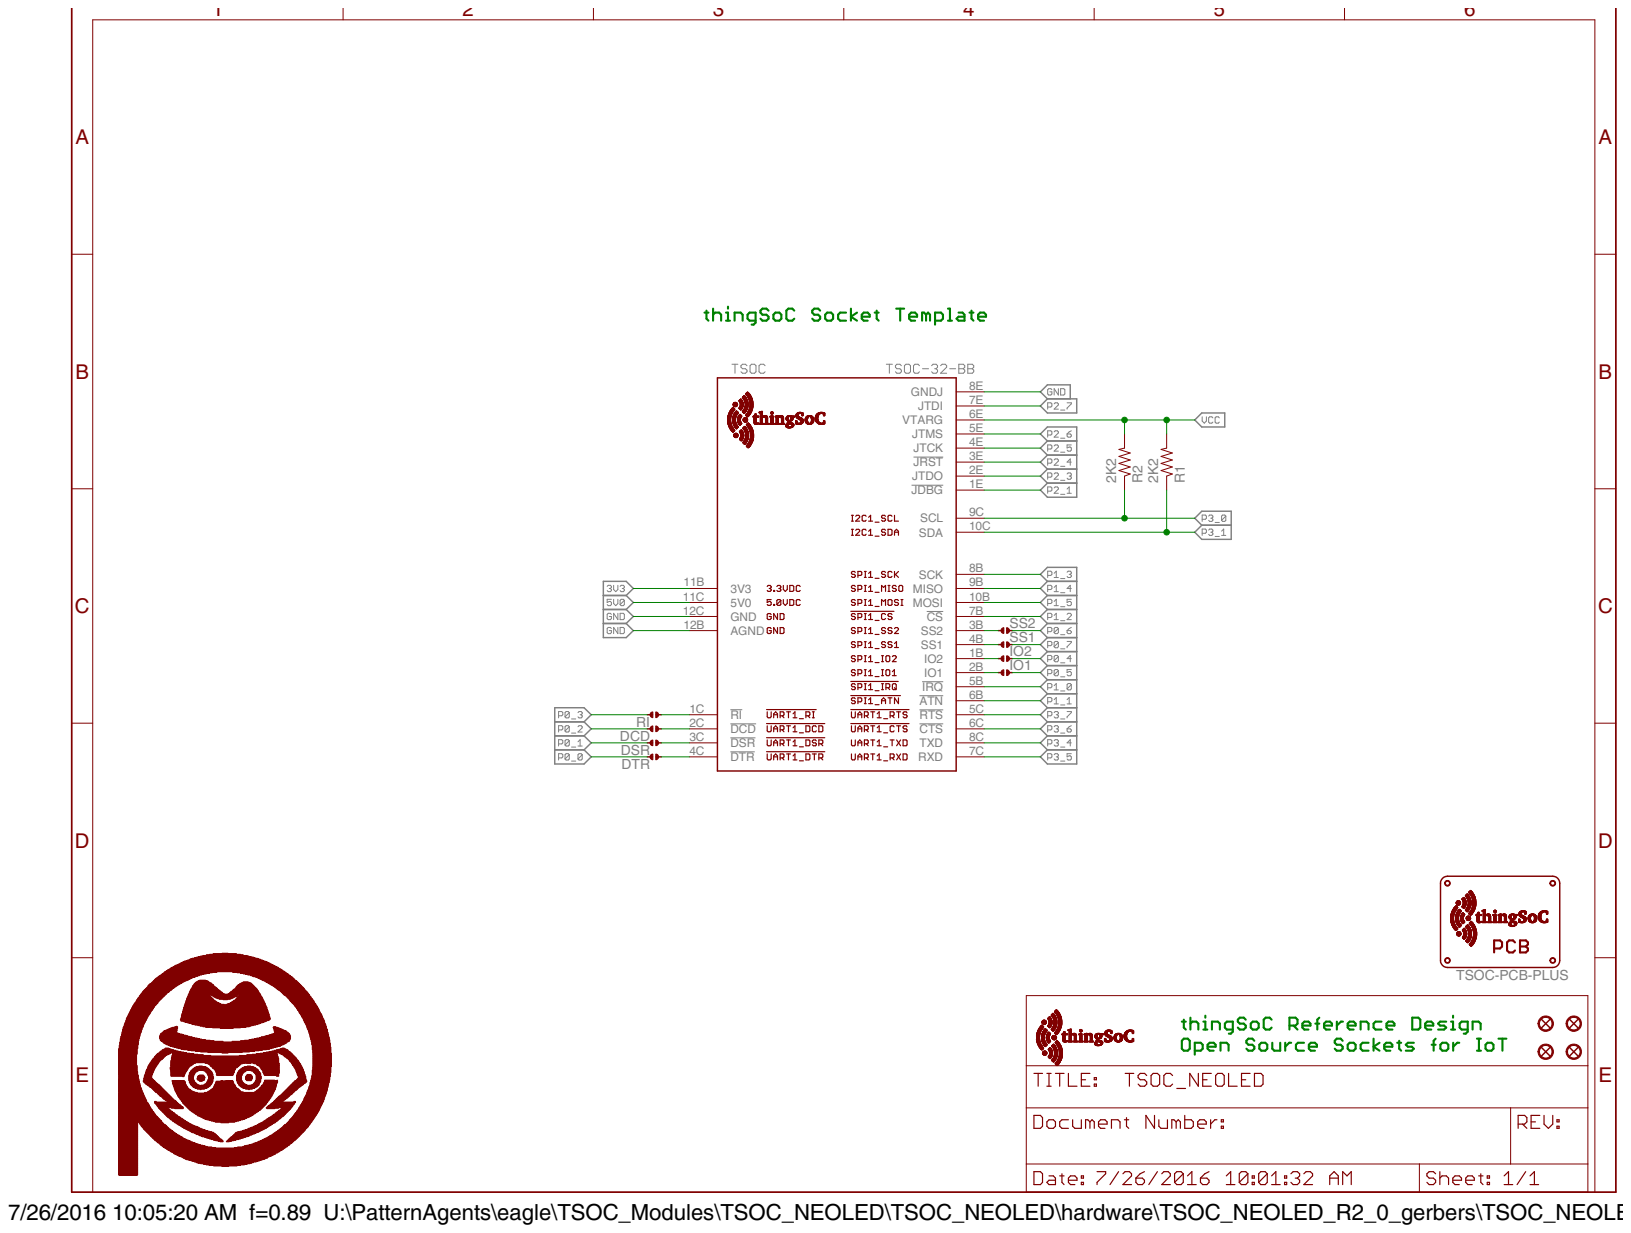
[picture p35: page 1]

7/26/2016 10:05:20 AM f=0.89 U:\PatternAgents\eagle\TSOC_Modules\TSOC_NEOLED\TSOC_NEOLED\hardware\TSOC_NEOLED_R2_0_gerbers\TSOC_NEOLED.sch (Sheet: 1/1)

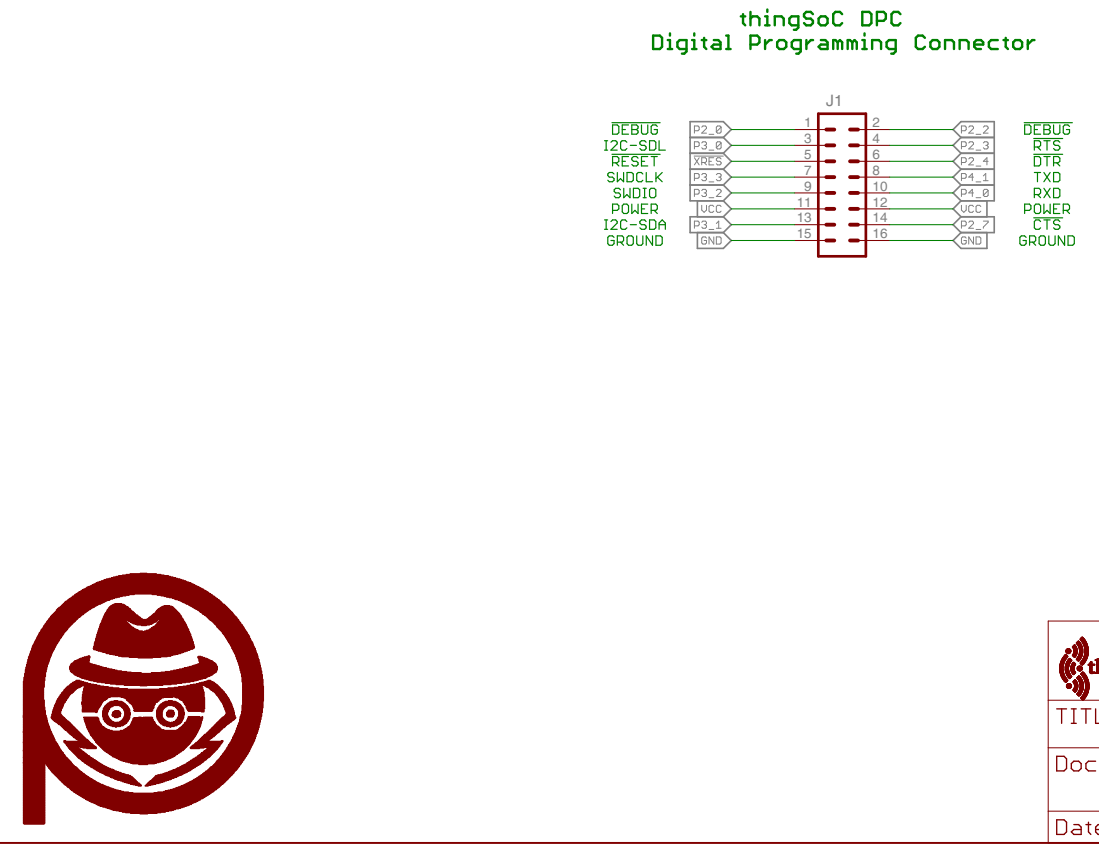
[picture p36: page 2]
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

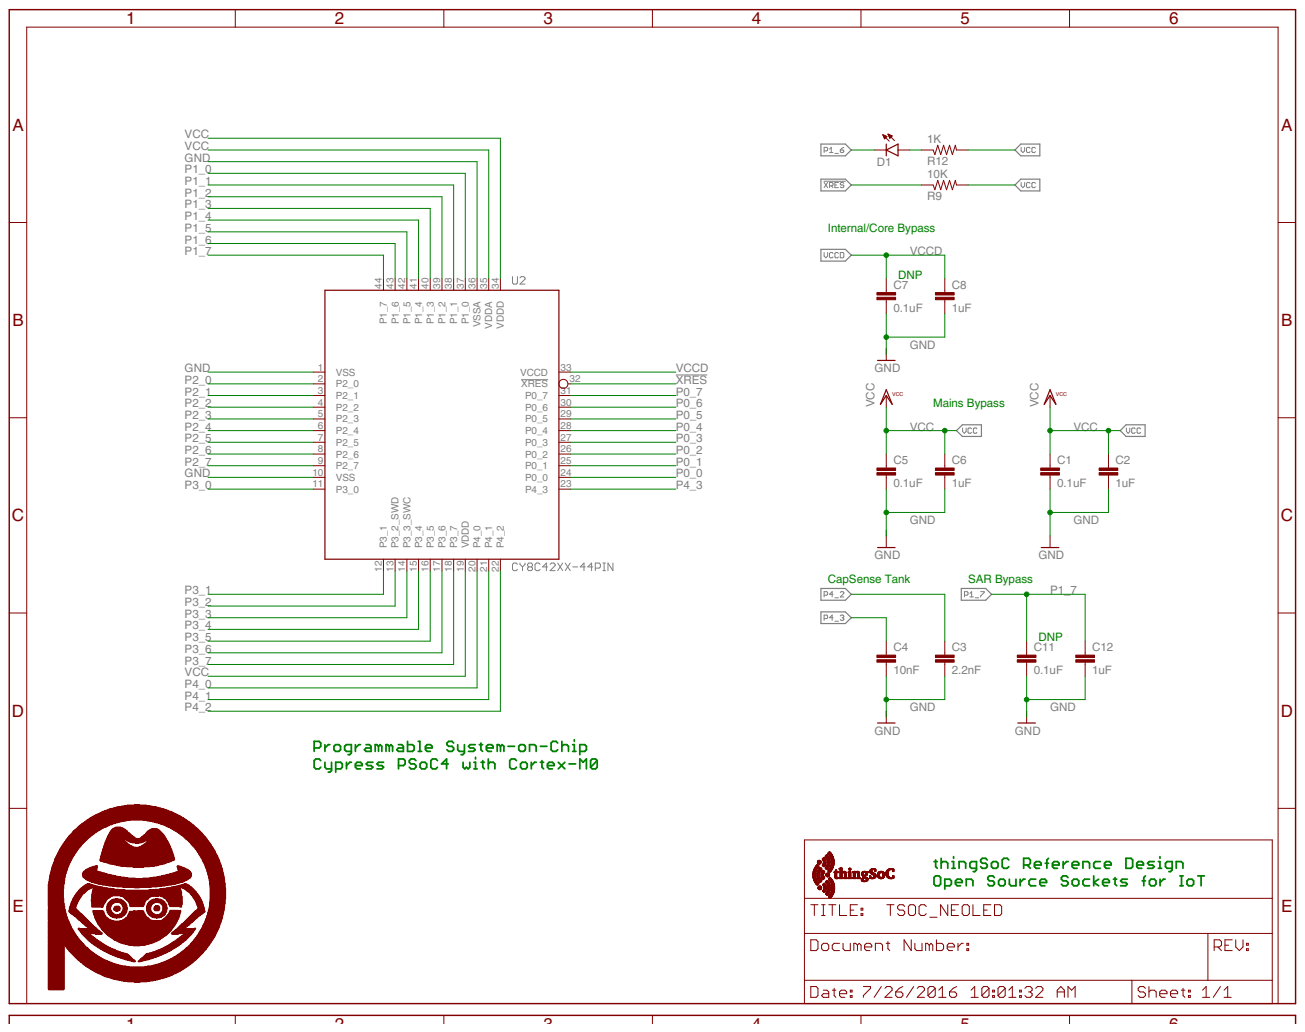
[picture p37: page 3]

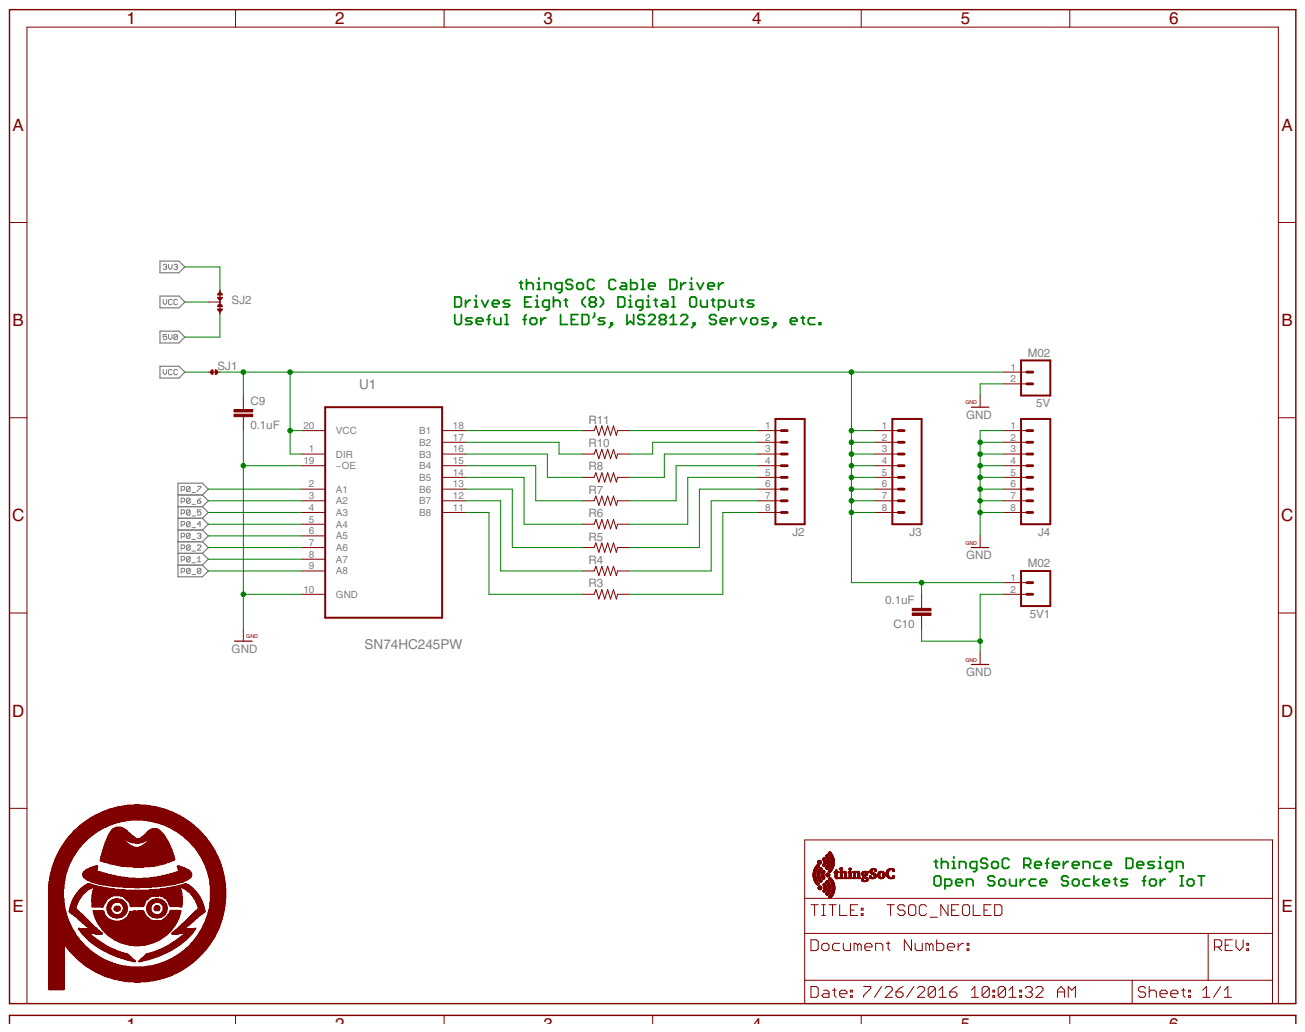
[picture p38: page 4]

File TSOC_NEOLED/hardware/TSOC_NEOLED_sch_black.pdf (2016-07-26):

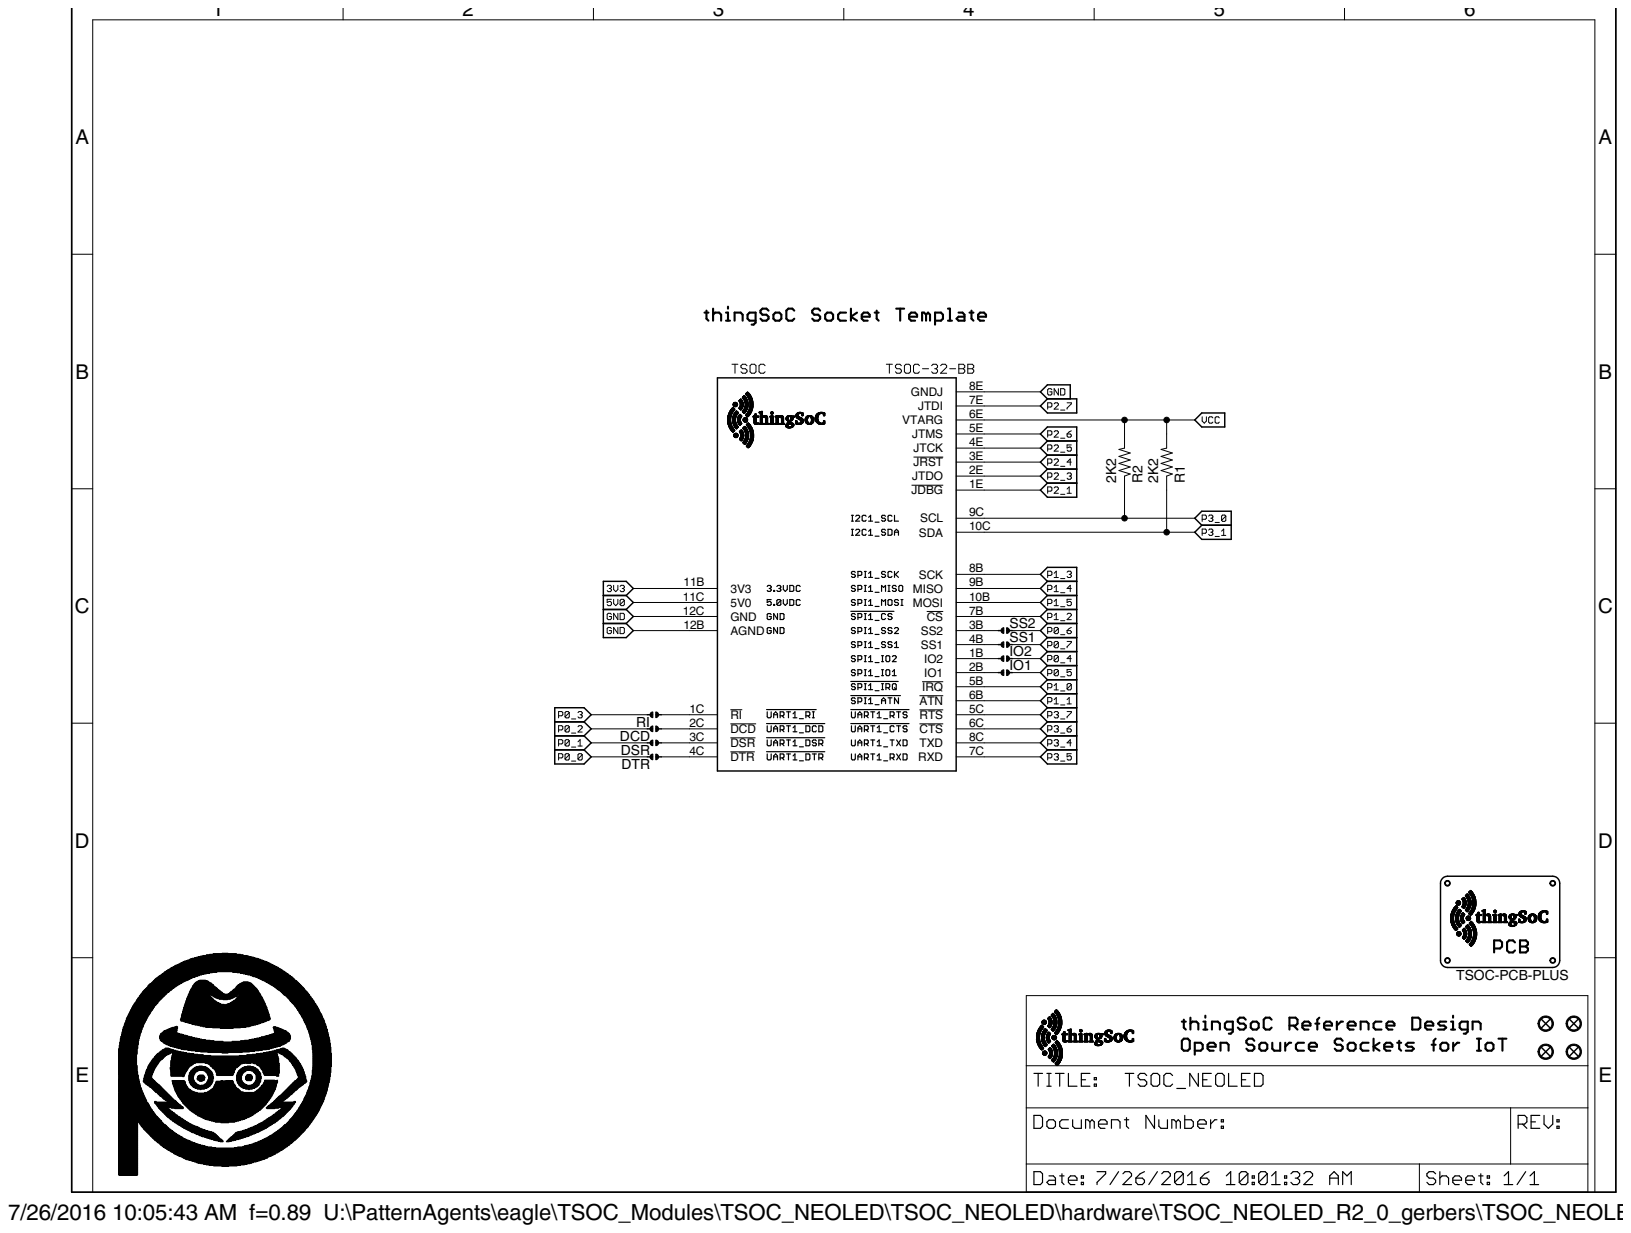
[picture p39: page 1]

7/26/2016 10:05:43 AM f=0.89 U:\PatternAgents\eagle\TSOC_Modules\TSOC_NEOLED\TSOC_NEOLED\hardware\TSOC_NEOLED_R2_0_gerbers\TSOC_NEOLED.sch (Sheet: 1/1)

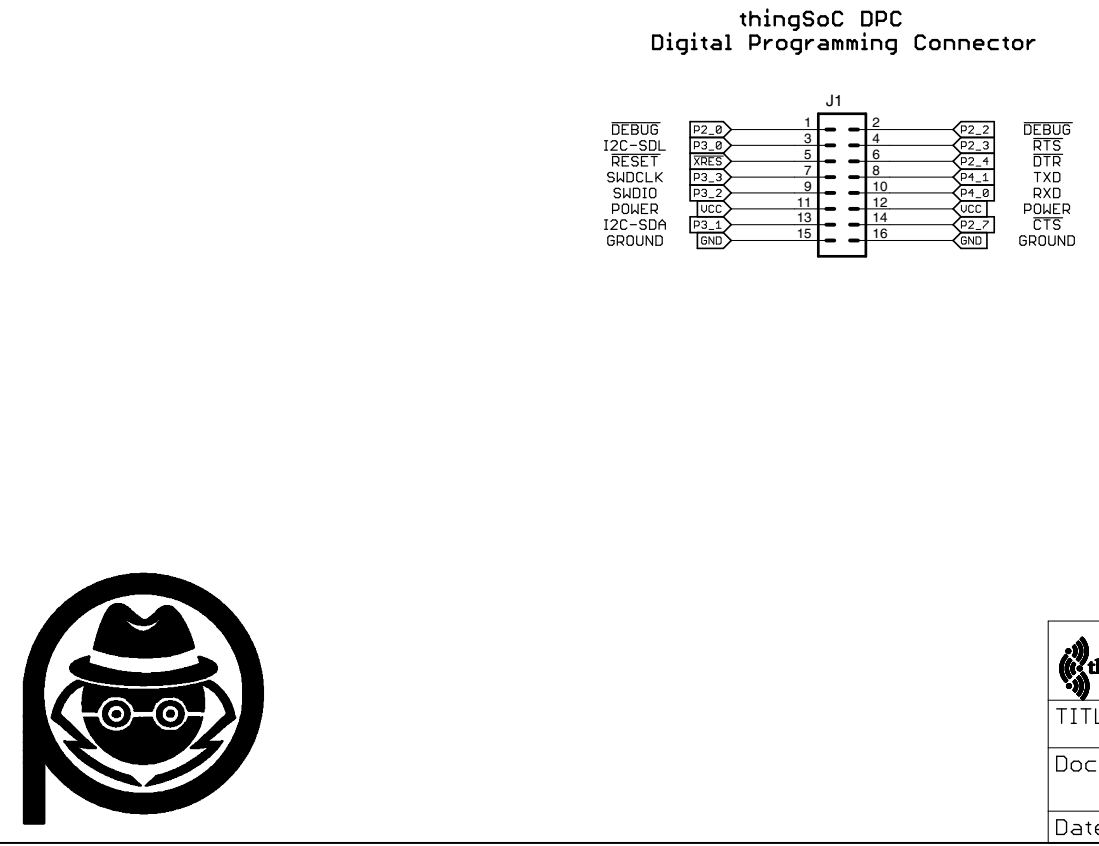
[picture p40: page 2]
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

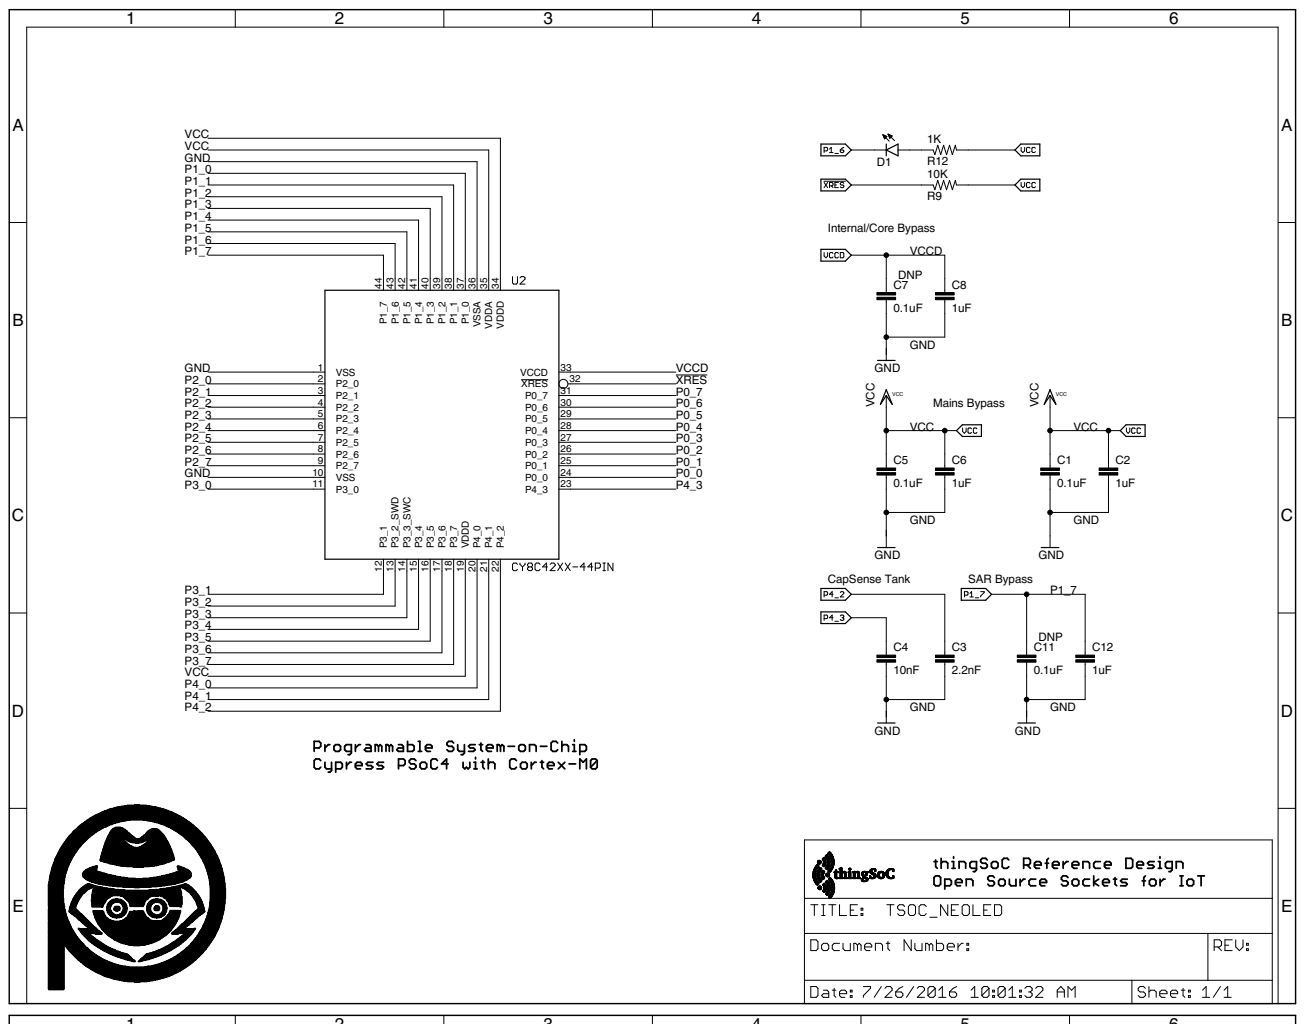
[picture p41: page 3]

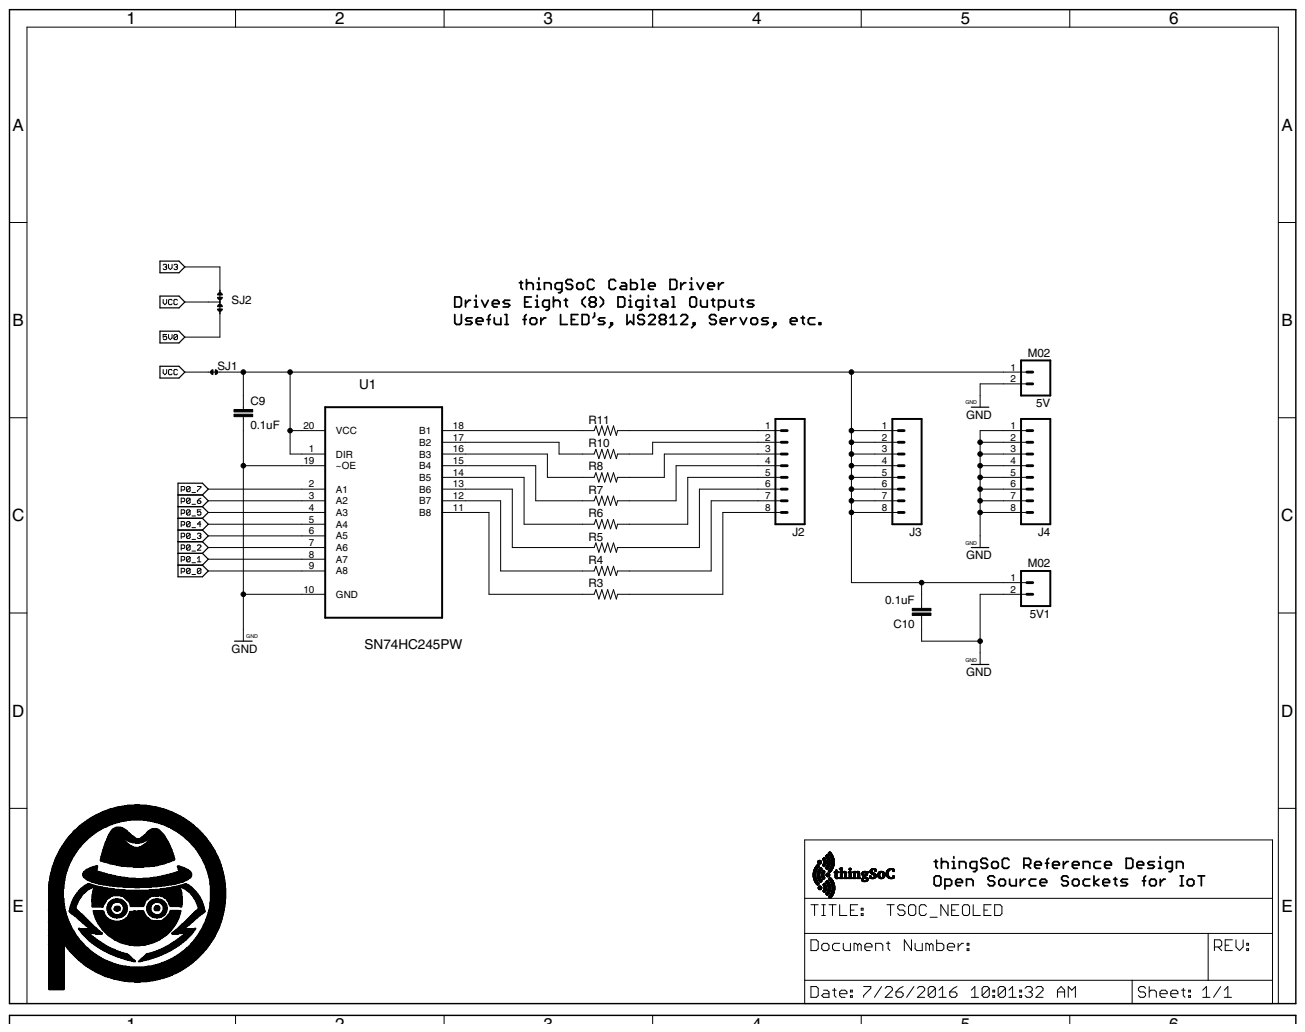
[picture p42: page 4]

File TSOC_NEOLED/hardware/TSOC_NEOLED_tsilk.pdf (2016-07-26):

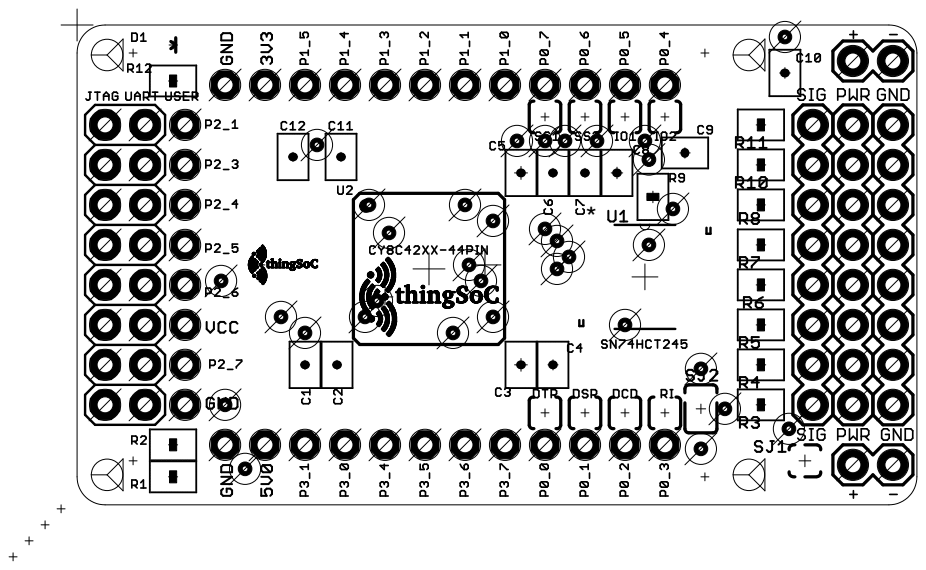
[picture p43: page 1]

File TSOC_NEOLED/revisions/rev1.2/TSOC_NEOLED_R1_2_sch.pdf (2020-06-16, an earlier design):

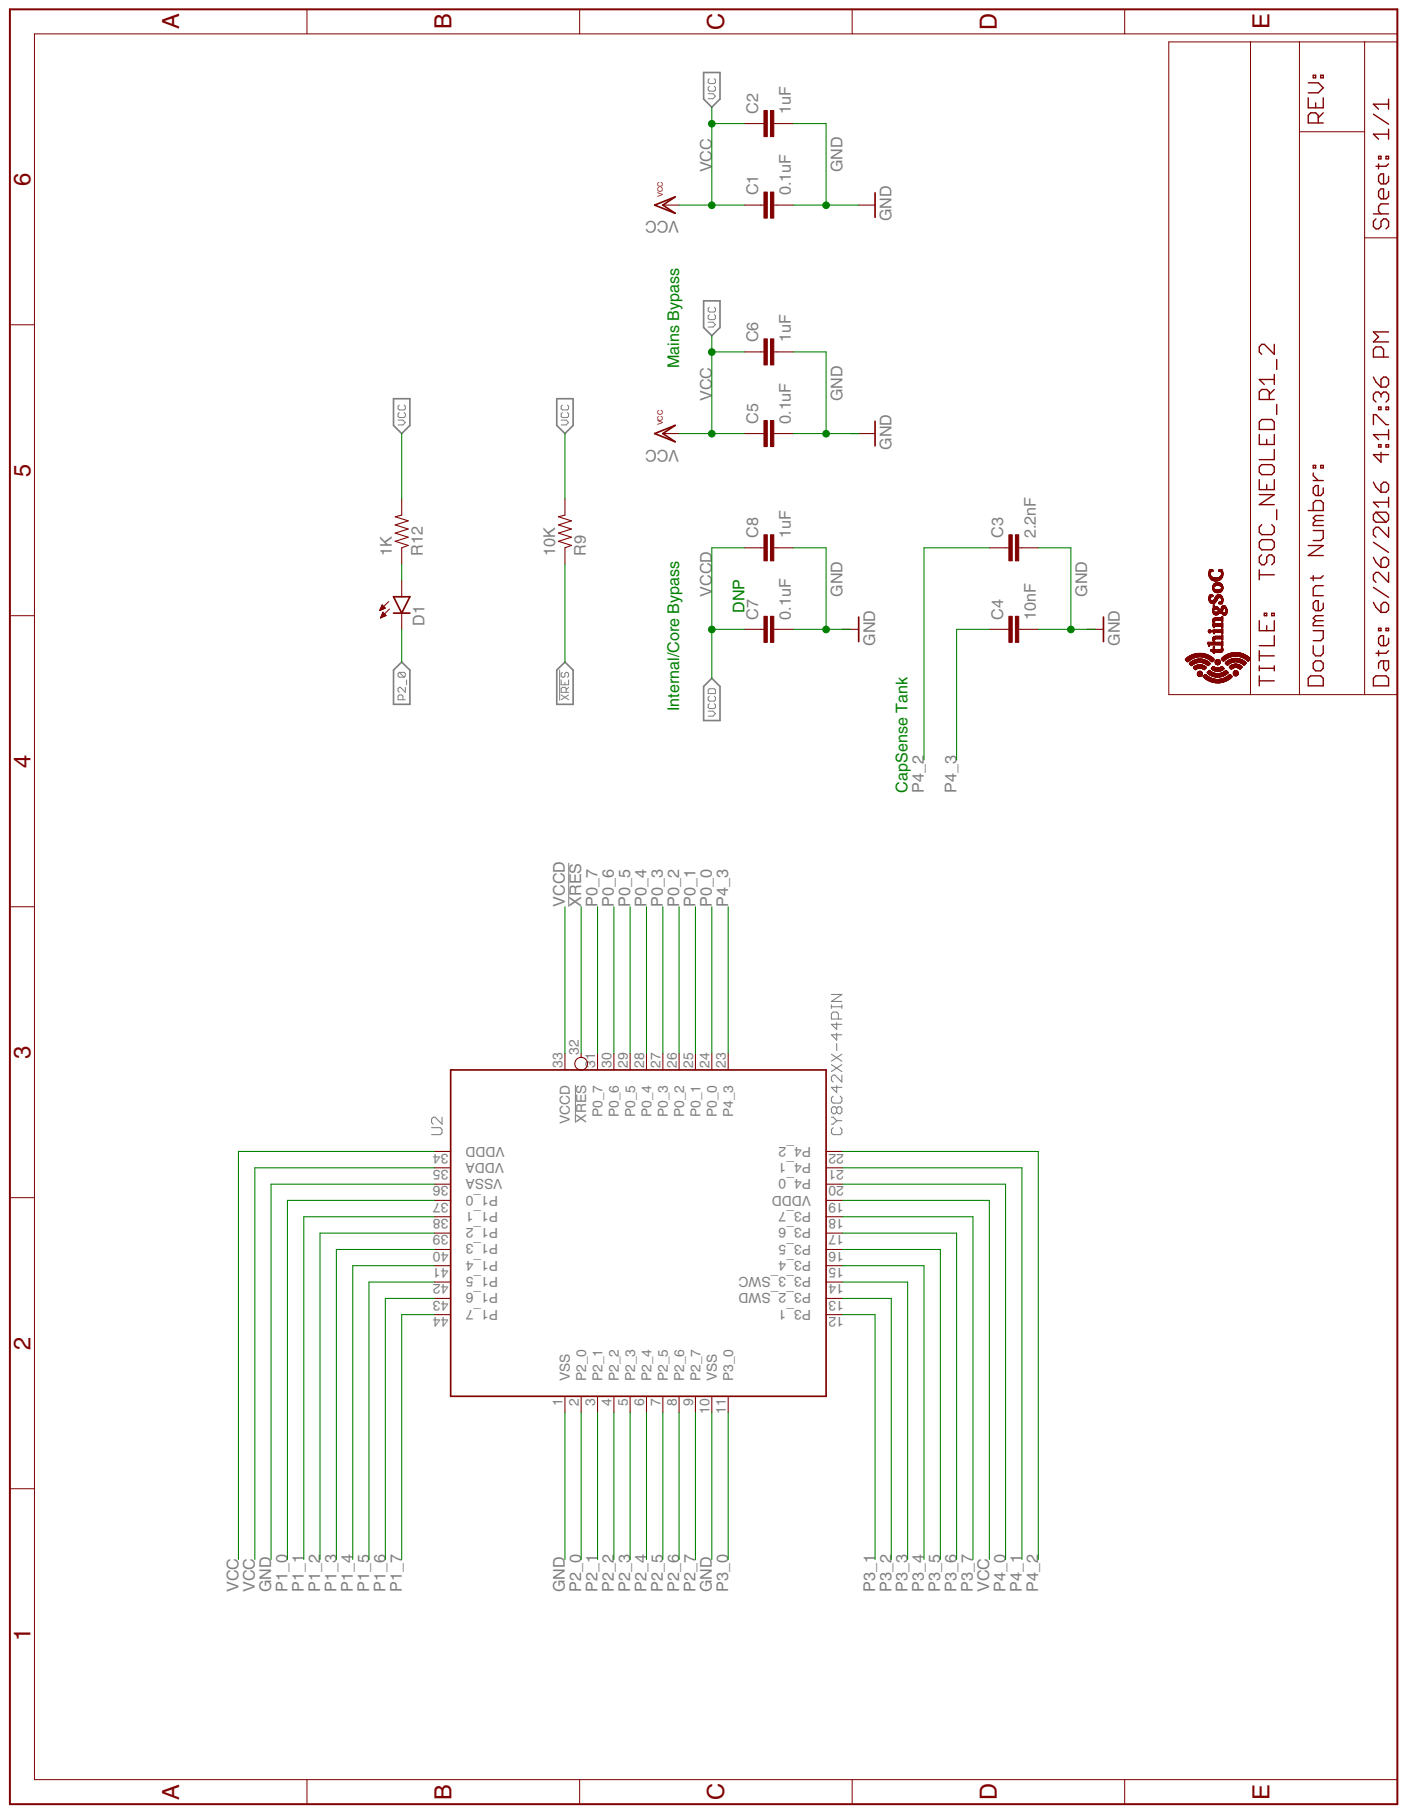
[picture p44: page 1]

SN74HC245PW GND GND 0.1uF 1uF 0.1uF 1uF 0.1uF 1uF GND GND GND 0.1uF CCV CCV M02 GND 10K 10nF 2.2nF GND 1K M02 M02 2K2 2K2 TSOC-PCB-PLUS M02 GND 0.1uF ATN 6B RI 1C DCD 2C DSR 3C DTR 4C TXD 8C IO2 1B IO1 2B RTS 5C CTS 6C IRQ 5B SS2 3B SS1 4B CS 7B MOSI 10B MISO 9B SCK 8B GND 12C AGND 12B 3V3 11B RXD 7C SDA 10C SCL 9C 5V0 11C JDBG 1E JTDO 2E JRST 3E JTCK 4E JTMS 5E VTARG 6E JTDI 7E GNDJ 8E VCC 20 DIR 1 ~OE 19 A1 2 A2 3 A3 4 A4 5 A5 6 A6 7 A7 8 A8 9 GND 10 B1 18 B2 17 B3 16 B4 15 B5 14 B6 13 B7 12 B8 11 U1 R11 R10 R8R7R6R5R4R3 VSS 1 P2_0 2 P2_1 3 P2_3 5 P2_4 6 P2_5 7 P2_7 9 VSS 10 P3_0 11 1_3P 21 D WS_2_3P 31 C WS_3_3P 41 4_3P 51 5_3P 61 7_3P 81 DDDV 91 0_4P 02 1_4P 12 2_4P 22 P4_3 23 P0_0 24 P0_1 25 P0_3 27 P0_4 28 P0_5 29 P0_7 31 XRES 32 VCCD 33 DDDV 43 ADDV 53 ASSV 63 0_1P 73 1_1P 83 3_1P 04 4_1P 14 5_1P 24 6_1P 34 7_1P 44 P2_2 4 P2_6 8 6_3P 71 P0_6 30 2_1P 93 P0_2 26 C1 C2 C5 C6 C7 C8 C9 J2 12345678 J4 12345678 J3 12345678 5V 12 J1 1 2 3 4 5 6 7 8 9 10 11 12 13 14 15 16 SJ2 RI DCD DSR DTR SS2 SS1 IO2 IO1 R9 C4 C3 R12 D1 SP2 21 SP1 21 2R1R 5V1 12 SJ1 C10 GND GND GND GND GND GND GND VCC VCC VCC VCC VCC P1_2 P1_7 P1_6 P1_5 P1_4 P1_3 P1_1 P1_0 P2_0 P2_1 P2_2 P2_3 P2_4 P2_5 P2_6 P2_7 P3_0 P3_1 P3_2 P3_3 P3_4 P3_5 P3_6 P3_7 P4_0 P4_1 P4_2 P4_2 P4_3 P4_3 P0_0 P0_1 P0_2 P0_3 P0_4 P0_5 P0_6 P0_7 XRES VCCD VCCD ABCDE ABCDE 1 2 3 4 5 6 ABCDE ABCDE 1 2 3 4 5 6 ABCDE ABCDE 1 2 3 4 5 6 ABCDE ABCDE 1 2 3 4 5 6 GND GND VCC VCC GND GND DNP Internal/Core Bypass Mains Bypass CapSense Tank




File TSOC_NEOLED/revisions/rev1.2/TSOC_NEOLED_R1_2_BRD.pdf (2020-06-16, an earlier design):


* RI DCD DSR DTR SS2 SS1 IO2 IO1 SJ1

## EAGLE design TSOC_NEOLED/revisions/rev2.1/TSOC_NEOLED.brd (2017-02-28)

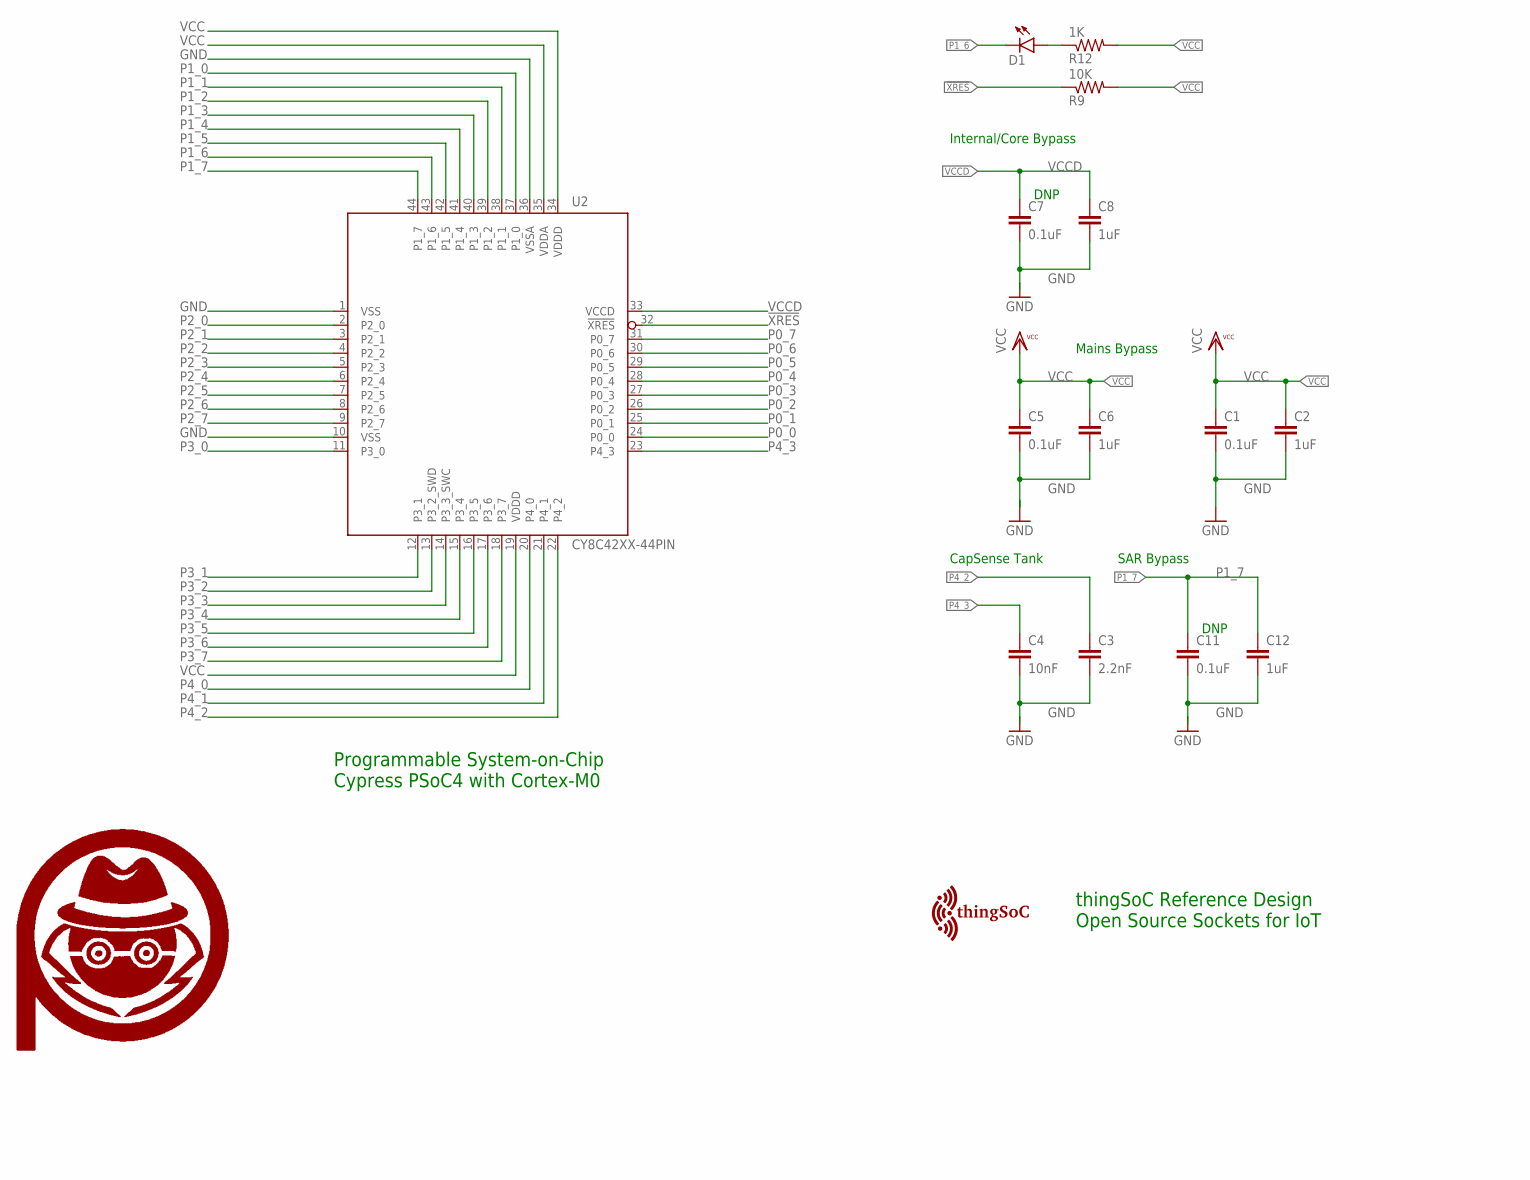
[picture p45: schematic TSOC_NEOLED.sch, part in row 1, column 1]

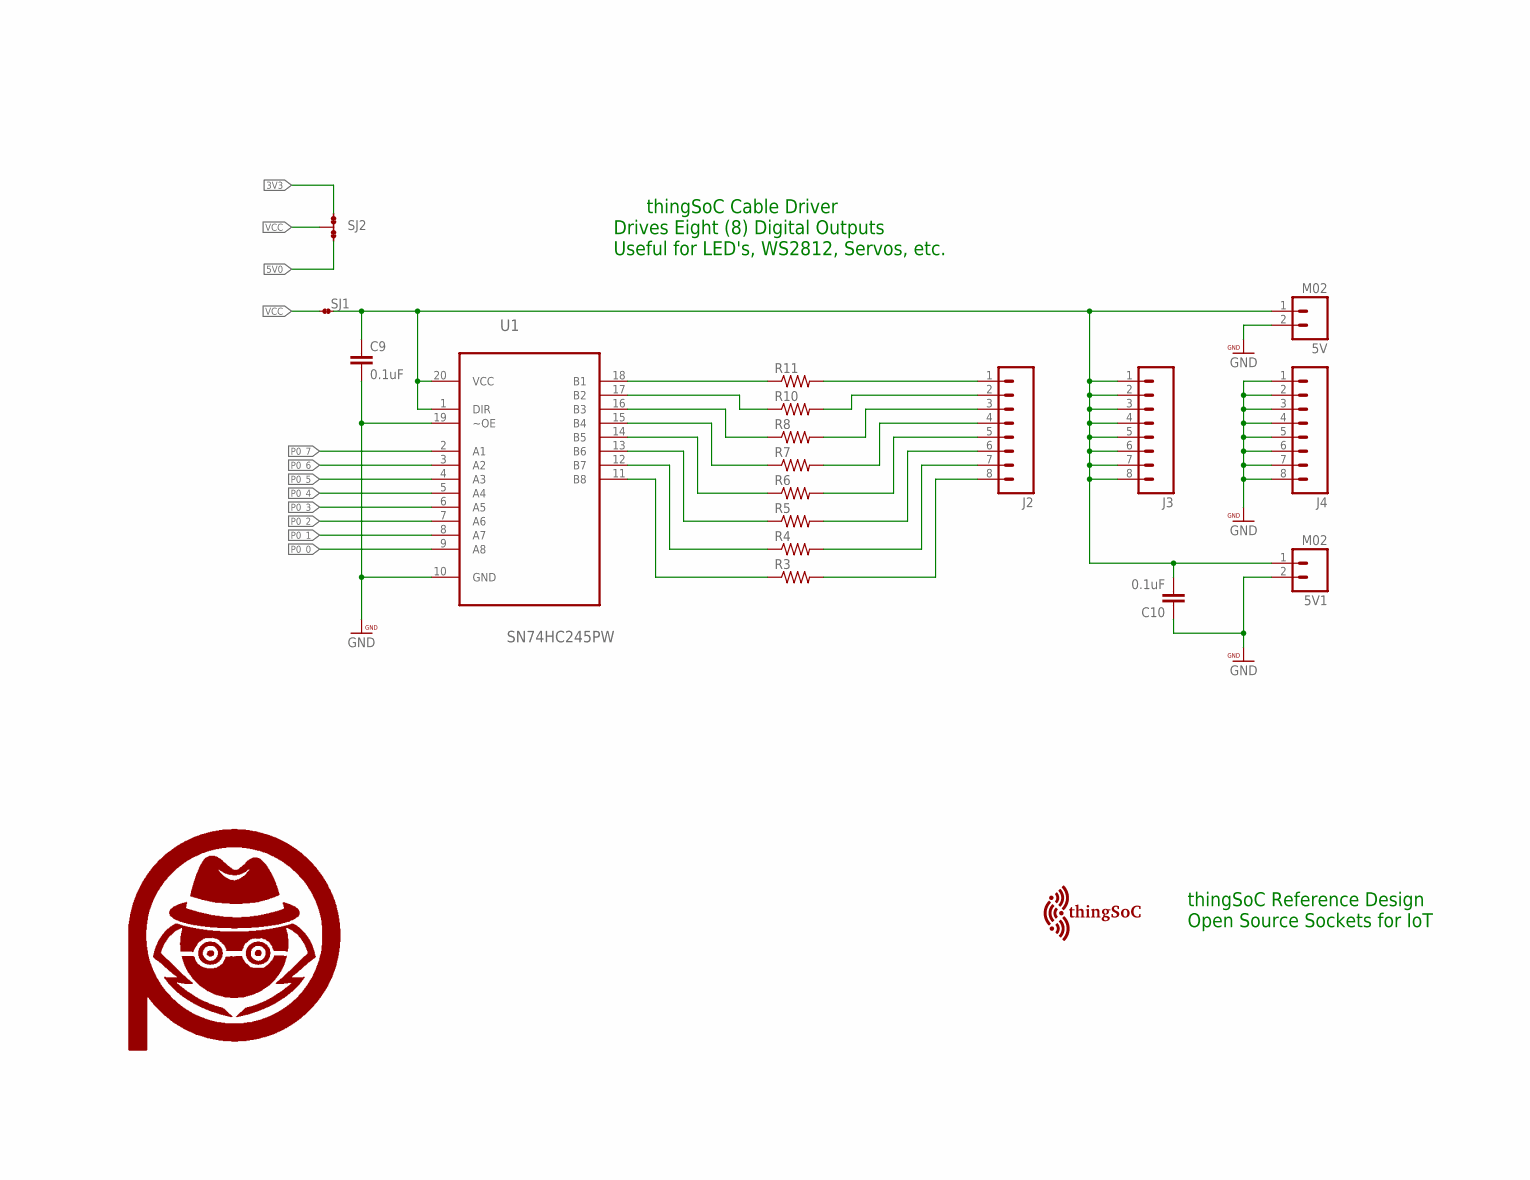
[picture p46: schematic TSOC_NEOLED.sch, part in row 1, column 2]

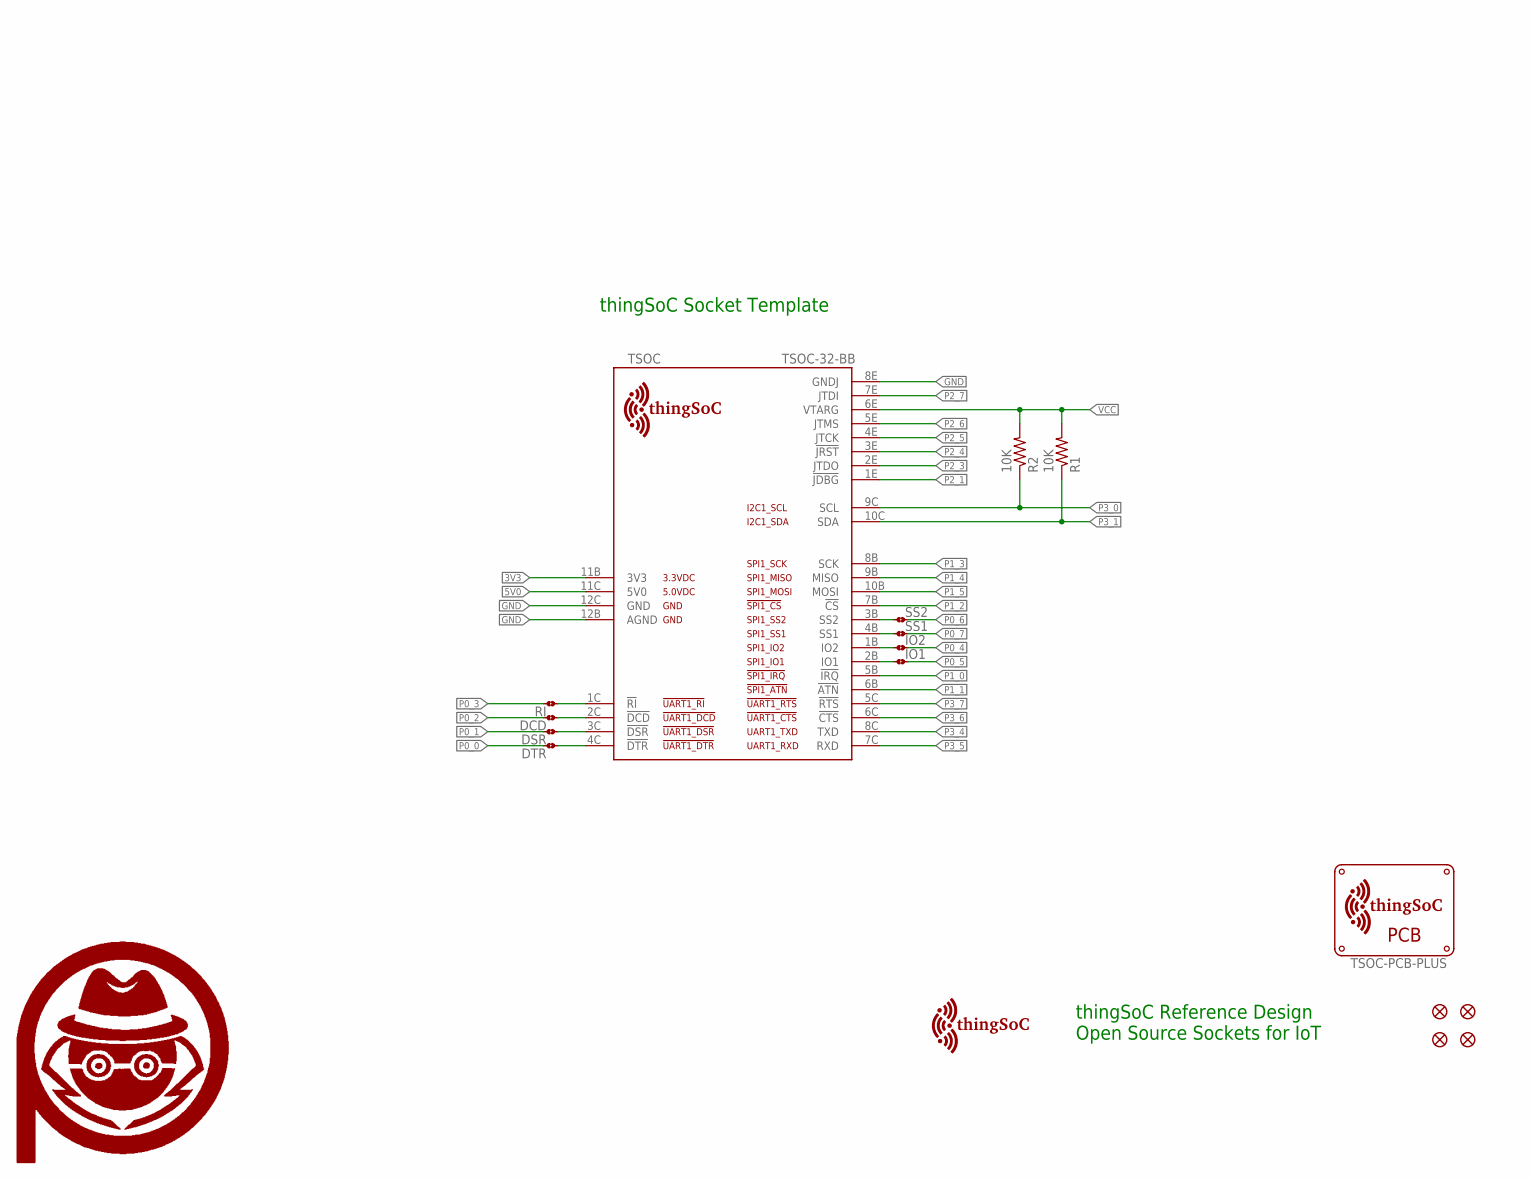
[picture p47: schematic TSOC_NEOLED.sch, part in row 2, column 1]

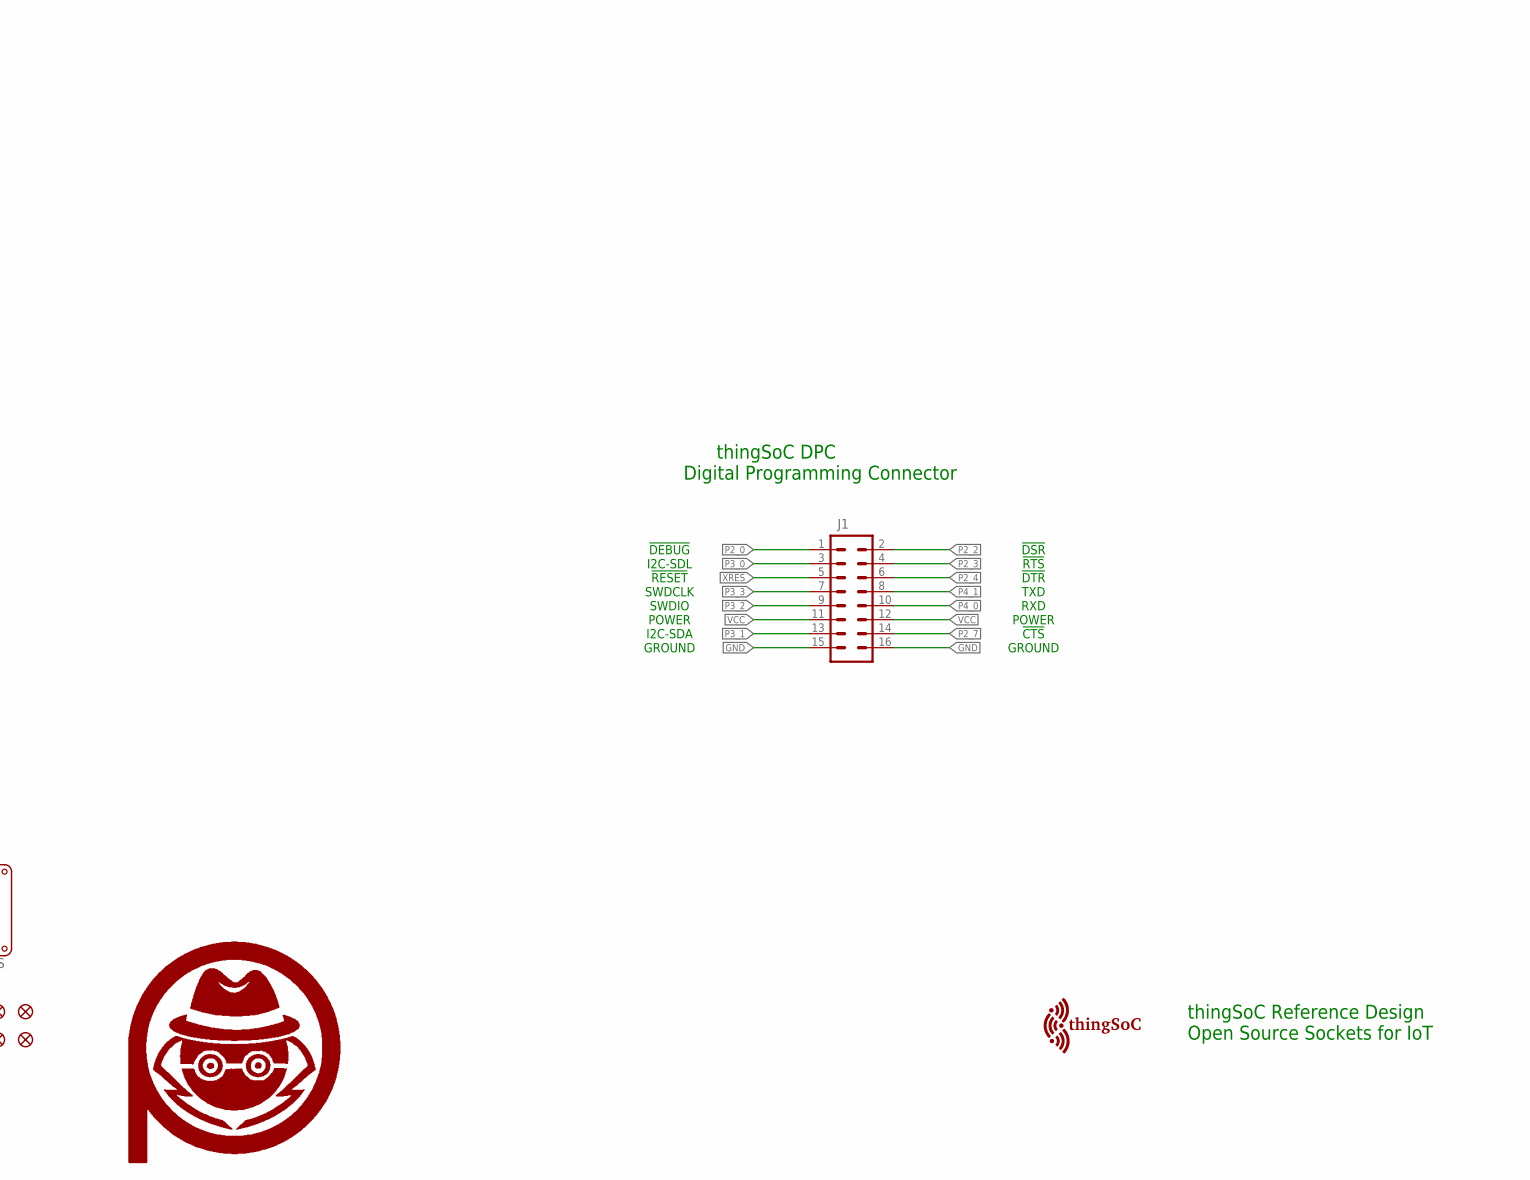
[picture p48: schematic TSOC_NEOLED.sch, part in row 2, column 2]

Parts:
5V, 5V1: M02; 1X02
$$U$1: TSOC-LOGO-SMALL; TSOC-LOGO-SML
$$U$2: TSOC-LOGO-MED
C1, C5, C7, C9, C10, C11: 0.1uF; 0603-CAP
C2, C6, C8, C12: 1uF; 0603-CAP
C3: 2.2nF; 0603-CAP
C4: 10nF; 0603-CAP
D1: LED0603; LED-0603
DCD: JMP-2-NO
DSR: JMP-2-NO
DTR: JMP-2-NO
FID1, FID2, FID3, FID4: FIDUCIALUFIDUCIAL; MICRO-FIDUCIAL
IO1, IO2: JMP-2-NO
J1: M08X2; 2X8
J2, J3, J4: M08; 1X08_ROUND
R1, R2, R9: 10K; 0603-RES
R3, R4, R5, R6, R7, R8, R10, R11: RESISTOR0603-RES; 0603-RES
R12: 1K; 0603-RES
RI: JMP-2-NO
SJ1: JMP-2-NC
SJ2: JMP-3-NC
SS1, SS2: JMP-2-NO
TSOC: TSOC-32-BB; TSOC-BB-S32
U1: SN74HC245PW; SOP65P640X120-20N
U2: CY8C42XX-44PIN; TQFP-10X10-44
U$1: TSOC-PCB-PLUS; TSOC-BB-BRD-PLUS
U$3, U$9, U$10, U$11: PA_LOGO_SYMNULL; NULL_SYM
U$100: TSOC-LOGO-SMALL; TSOC-LOGO-SML
U$101: TSOC-LOGO-LRG

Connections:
3V3: SJ2.1, TSOC.11B (3V3)
5V0: SJ2.3, TSOC.11C (5V0)
!DCD: DCD.1, TSOC.2C (!DCD)
!DSR: DSR.1, TSOC.3C (!DSR)
!DTR: DTR.1, TSOC.4C (!DTR)
!R!: RI.1, TSOC.1C (!RI)
!XRES: J1.5, R9.1, U2.32 (!XRES)
GND: 5V.2, 5V1.2, C1.2, C2.2, C3.2, C4.2, C5.2, C6.2, C7.2, C8.2, C9.2, C10.1, C11.2, C12.2, J1.15, J1.16, J4.1, J4.2, J4.3, J4.4, J4.5, J4.6, J4.7, J4.8, TSOC.8E (GNDJ), TSOC.12B (AGND), TSOC.12C (GND), U1.10 (GND), U1.19 (~OE), U2.1 (VSS), U2.10 (VSS), U2.36 (VSSA)
IO1: IO1.1, TSOC.2B (IO1)
IO2: IO2.1, TSOC.1B (IO2)
unnamed: J2.1, R11.2
unnamed: J2.2, R10.2
unnamed: J2.3, R8.2
unnamed: J2.4, R7.2
unnamed: J2.5, R6.2
unnamed: J2.6, R5.2
unnamed: J2.7, R4.2
unnamed: J2.8, R3.2
unnamed: R11.1, U1.18 (B1)
unnamed: R10.1, U1.17 (B2)
unnamed: R8.1, U1.16 (B3)
unnamed: R7.1, U1.15 (B4)
unnamed: R6.1, U1.14 (B5)
unnamed: R5.1, U1.13 (B6)
unnamed: R4.1, U1.12 (B7)
unnamed: R3.1, U1.11 (B8)
unnamed: D1.A, R12.1
P0_0: DTR.2, U1.9 (A8), U2.24 (P0_0)
P0_1: DSR.2, U1.8 (A7), U2.25 (P0_1)
P0_2: DCD.2, U1.7 (A6), U2.26 (P0_2)
P0_3: RI.2, U1.6 (A5), U2.27 (P0_3)
P0_4: IO2.2, U1.5 (A4), U2.28 (P0_4)
P0_5: IO1.2, U1.4 (A3), U2.29 (P0_5)
P0_6: SS2.2, U1.3 (A2), U2.30 (P0_6)
P0_7: SS1.2, U1.2 (A1), U2.31 (P0_7)
P1_0: TSOC.5B (!IRQ), U2.37 (P1_0)
P1_1: TSOC.6B (!ATN), U2.38 (P1_1)
P1_2: TSOC.7B (!CS), U2.39 (P1_2)
P1_3: TSOC.8B (SCK), U2.40 (P1_3)
P1_4: TSOC.9B (MISO), U2.41 (P1_4)
P1_5: TSOC.10B (MOSI), U2.42 (P1_5)
P1_6: D1.C, U2.43 (P1_6)
P1_7: C11.1, C12.1, U2.44 (P1_7)
P2_0: J1.1, U2.2 (P2_0)
P2_1: TSOC.1E (!JDBG), U2.3 (P2_1)
P2_2: J1.2, U2.4 (P2_2)
P2_3: J1.4, TSOC.2E (JTDO), U2.5 (P2_3)
P2_4: J1.6, TSOC.3E (!JRST), U2.6 (P2_4)
P2_5: TSOC.4E (JTCK), U2.7 (P2_5)
P2_6: TSOC.5E (JTMS), U2.8 (P2_6)
P2_7: J1.14, TSOC.7E (JTDI), U2.9 (P2_7)
P3_0: J1.3, R2.1, TSOC.9C (SCL), U2.11 (P3_0)
P3_1: J1.13, R1.1, TSOC.10C (SDA), U2.12 (P3_1)
P3_2: J1.9, U2.13 (P3_2_SWD)
P3_3: J1.7, U2.14 (P3_3_SWC)
P3_4: TSOC.8C (TXD), U2.15 (P3_4)
P3_5: TSOC.7C (RXD), U2.16 (P3_5)
P3_6: TSOC.6C (!CTS), U2.17 (P3_6)
P3_7: TSOC.5C (!RTS), U2.18 (P3_7)
P4_0: J1.10, U2.20 (P4_0)
P4_1: J1.8, U2.21 (P4_1)
P4_2: C3.1, U2.22 (P4_2)
P4_3: C4.1, U2.23 (P4_3)
SS1: SS1.1, TSOC.4B (SS1)
SS2: SS2.1, TSOC.3B (SS2)
VCC: C1.1, C2.1, C5.1, C6.1, J1.11, J1.12, R1.2, R2.2, R9.2, R12.2, SJ1.1, SJ2.2, TSOC.6E (VTARG), U2.19 (VDDD), U2.34 (VDDD), U2.35 (VDDA)
VCCD: C7.1, C8.1, U2.33 (VCCD)
VEXT: 5V.1, 5V1.1, C9.1, C10.2, J3.1, J3.2, J3.3, J3.4, J3.5, J3.6, J3.7, J3.8, SJ1.2, U1.1 (DIR), U1.20 (VCC)

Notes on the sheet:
DNP
Internal/Core Bypass
Mains Bypass
I2C-SDA
I2C-SDL
!RESET
SWDCLK
SWDIO
POWER
GROUND
!DEBUG
!DSR
!RTS
!CTS
!DTR
TXD
RXD
CapSense Tank
thingSoC Reference Design Open Source Sockets for IoT
SAR Bypass
thingSoC DPC Digital Programming Connector
thingSoC Cable Driver Drives Eight (8) Digital Outputs Useful for LED's, WS2812, Servos, etc.
thingSoC Socket Template
Programmable System-on-Chip Cypress PSoC4 with Cortex-M0

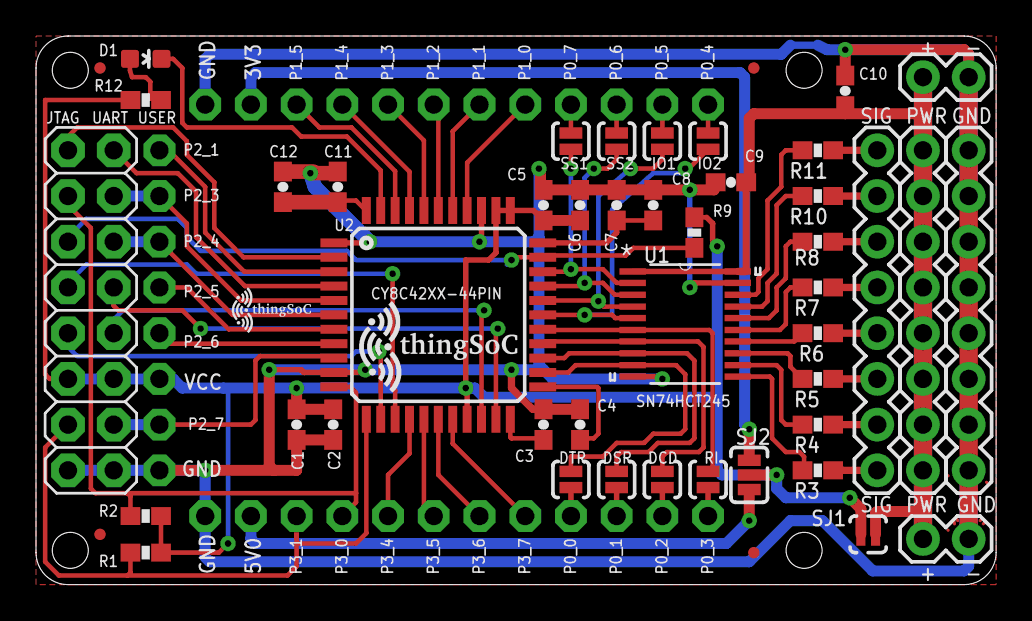
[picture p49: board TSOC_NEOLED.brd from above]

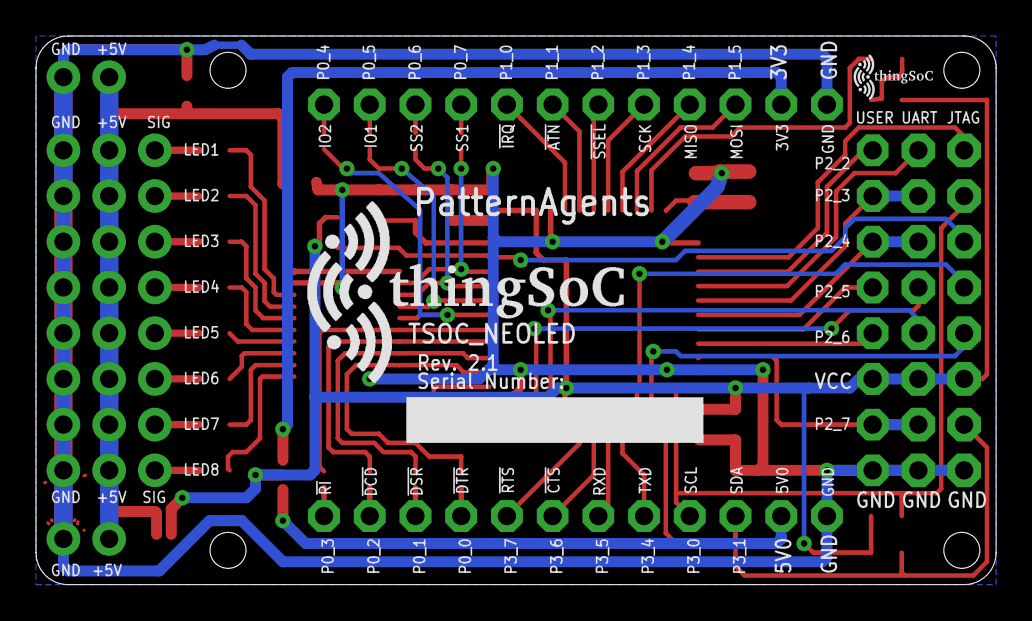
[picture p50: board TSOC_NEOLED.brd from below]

Board: 2 copper layers, 53.3 x 30.5 mm, 57 parts (2 on the bottom side), 68 nets.

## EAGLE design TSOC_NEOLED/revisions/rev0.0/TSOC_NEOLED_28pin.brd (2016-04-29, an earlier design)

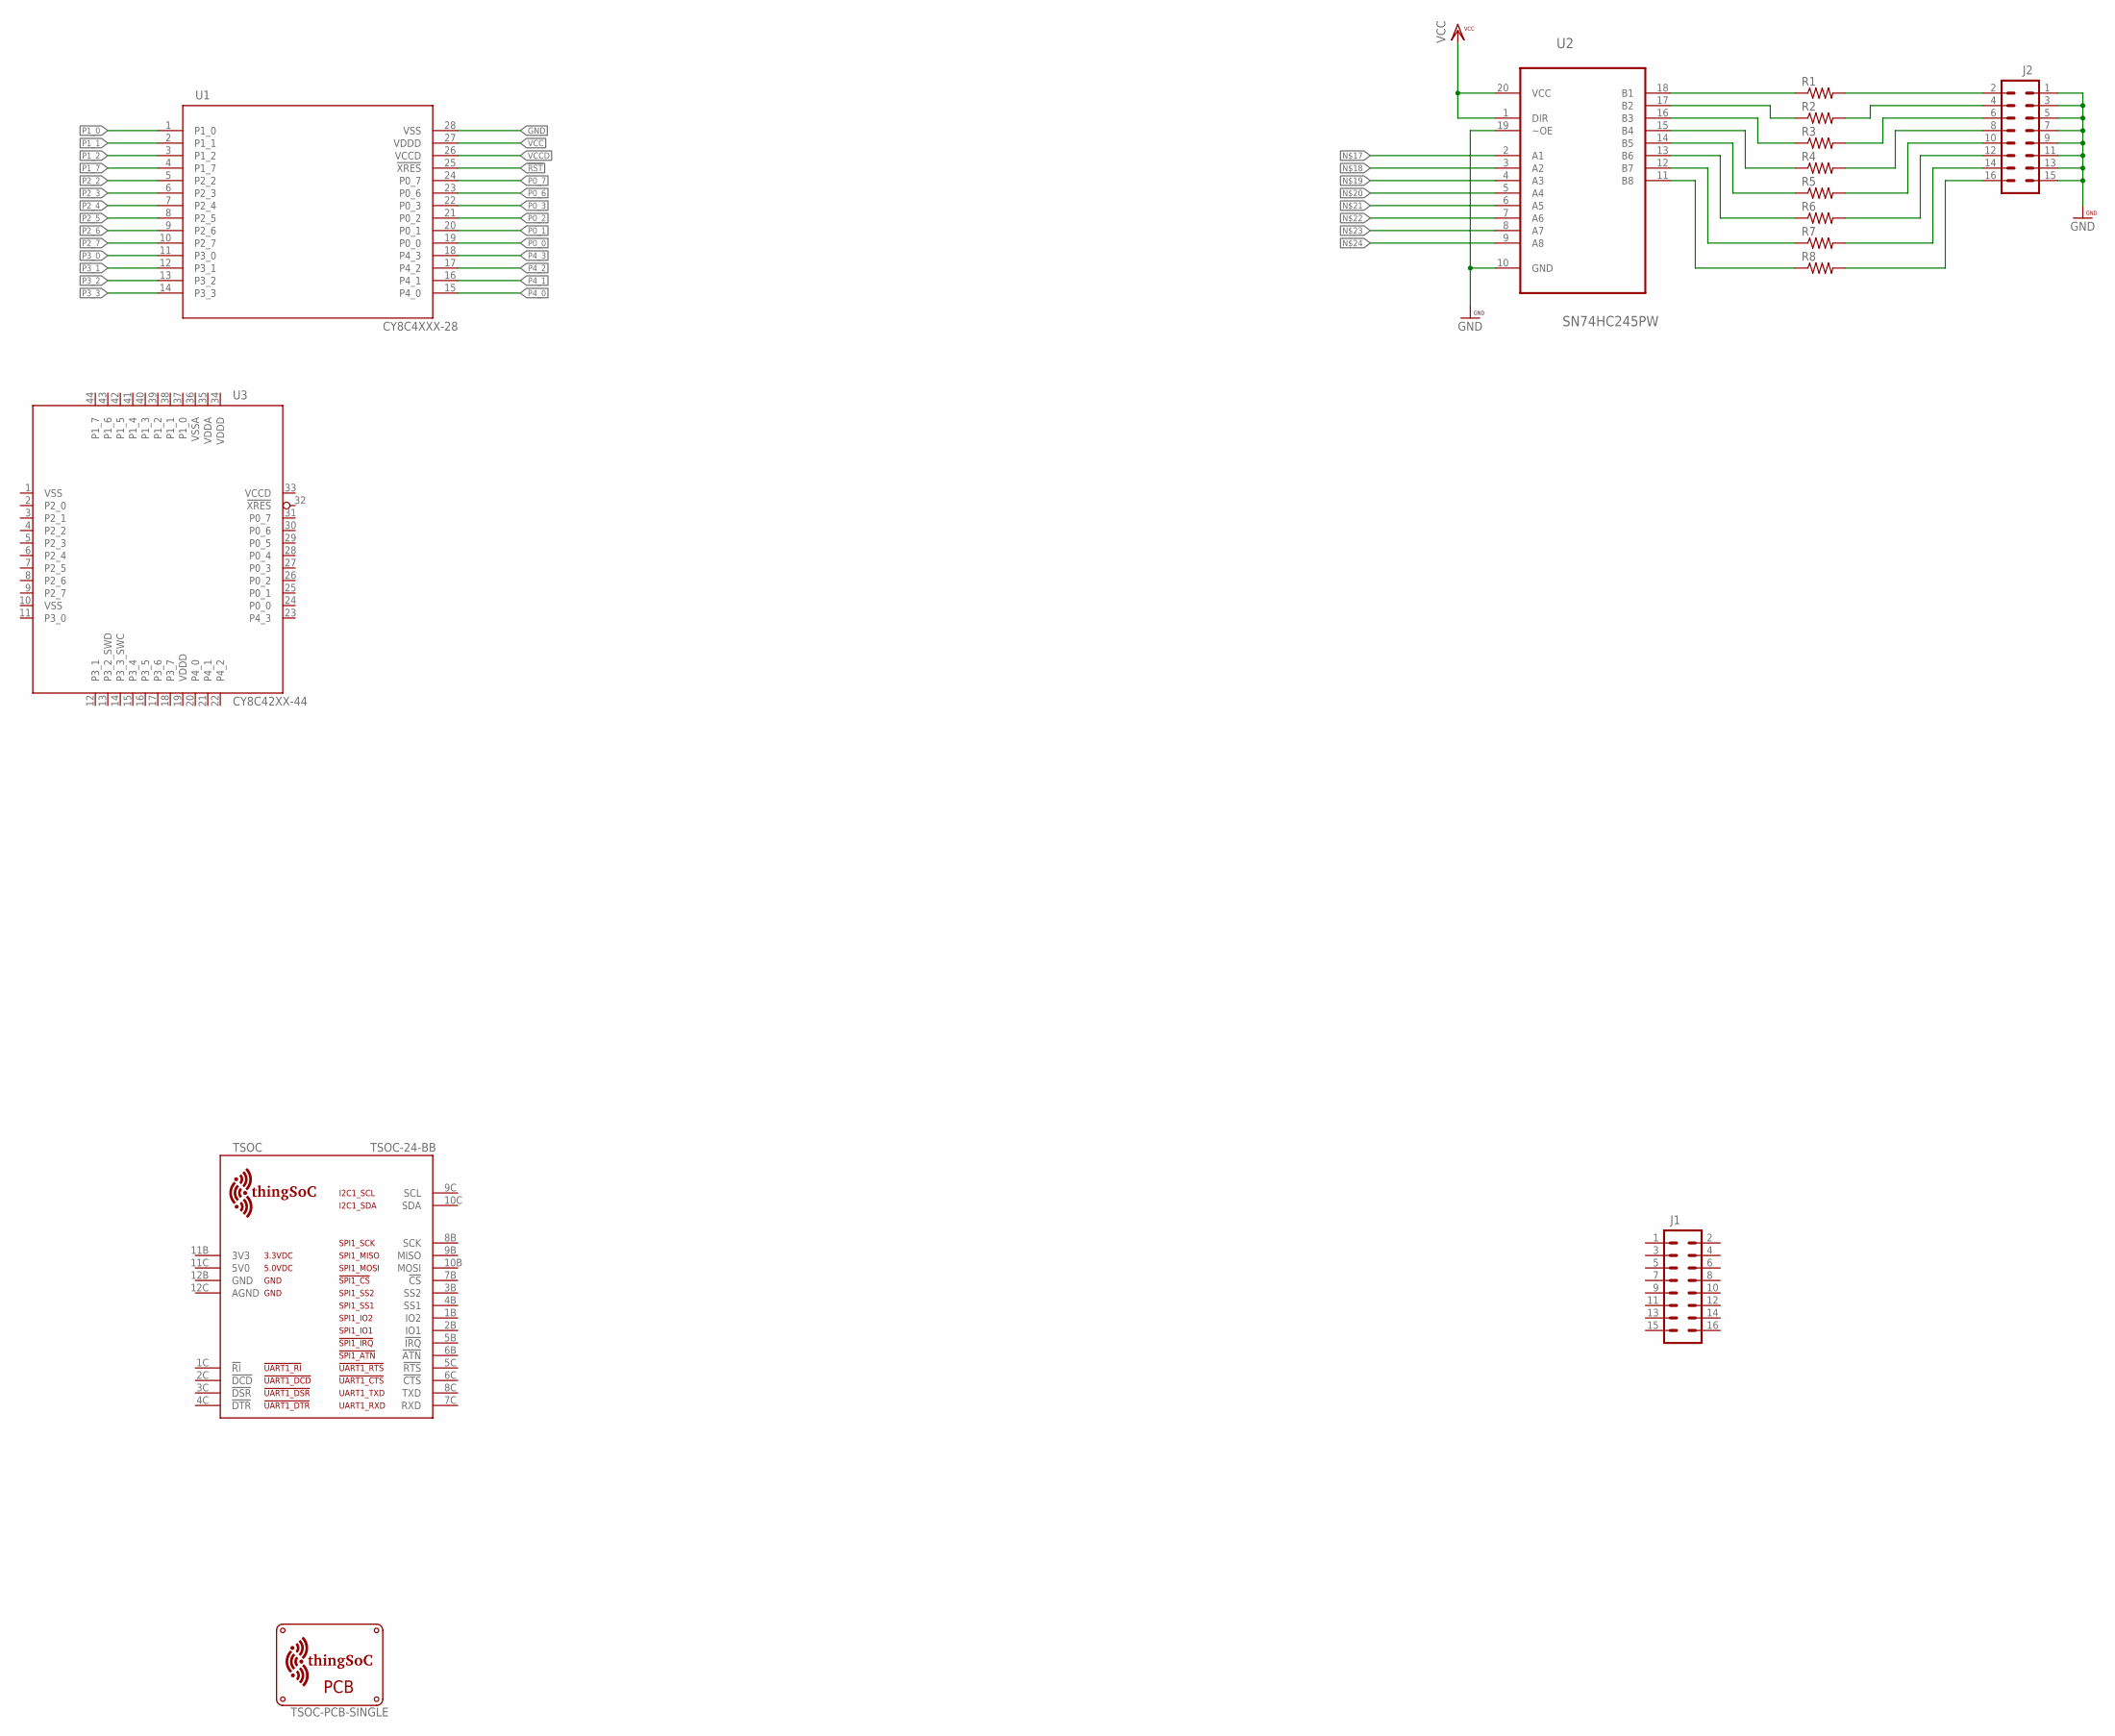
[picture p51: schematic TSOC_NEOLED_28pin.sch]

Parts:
J1, J2: M08X2; 2X8
R1, R2, R3, R4, R5, R6, R7, R8: RESISTOR0603-RES; 0603-RES
TSOC: TSOC-24-BB; TSOC-BB-S24
U1: CY8C4XXX-28; SSOP28
U2: SN74HC245PW; SOP65P640X120-20N
U3: CY8C42XX-44; TQFP-10X10-44
U$3: TSOC-PCB-SINGLE; TSOC-BB-BRD

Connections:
!RST: U1.25 (!XRES)
GND: J2.1, J2.3, J2.5, J2.7, J2.9, J2.11, J2.13, J2.15, U1.28 (VSS), U2.10 (GND), U2.19 (~OE)
unnamed: J2.2, R1.2
unnamed: J2.4, R2.2
unnamed: J2.6, R3.2
unnamed: J2.8, R4.2
unnamed: J2.10, R5.2
unnamed: J2.12, R6.2
unnamed: J2.14, R7.2
unnamed: J2.16, R8.2
unnamed: R1.1, U2.18 (B1)
unnamed: R2.1, U2.17 (B2)
unnamed: R3.1, U2.16 (B3)
unnamed: R4.1, U2.15 (B4)
unnamed: R5.1, U2.14 (B5)
unnamed: R6.1, U2.13 (B6)
unnamed: R7.1, U2.12 (B7)
unnamed: R8.1, U2.11 (B8)
P0_0: U1.19 (P0_0)
P0_1: U1.20 (P0_1)
P0_2: U1.21 (P0_2)
P0_3: U1.22 (P0_3)
P0_6: U1.23 (P0_6), U3.30 (P0_6)
P0_7: U1.24 (P0_7)
P1_0: U1.1 (P1_0)
P1_1: U1.2 (P1_1)
P1_2: U1.3 (P1_2), U3.39 (P1_2)
P1_7: U1.4 (P1_7)
P2_2: U1.5 (P2_2), U3.4 (P2_2)
P2_3: U1.6 (P2_3)
P2_4: U1.7 (P2_4)
P2_5: U1.8 (P2_5)
P2_6: U1.9 (P2_6), U3.8 (P2_6)
P2_7: U1.10 (P2_7)
P3_0: U1.11 (P3_0)
P3_1: U1.12 (P3_1)
P3_2: U1.13 (P3_2)
P3_3: U1.14 (P3_3)
P3_6: U3.17 (P3_6)
P4_0: U1.15 (P4_0)
P4_1: U1.16 (P4_1)
P4_2: U1.17 (P4_2)
P4_3: U1.18 (P4_3)
VCC: U1.27 (VDDD), U2.1 (DIR), U2.20 (VCC)
VCCD: U1.26 (VCCD)

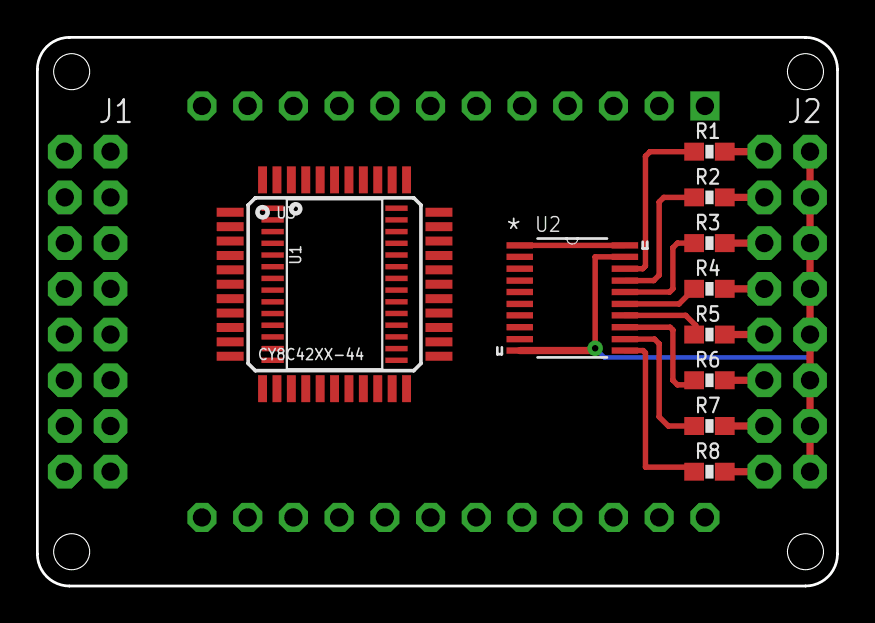
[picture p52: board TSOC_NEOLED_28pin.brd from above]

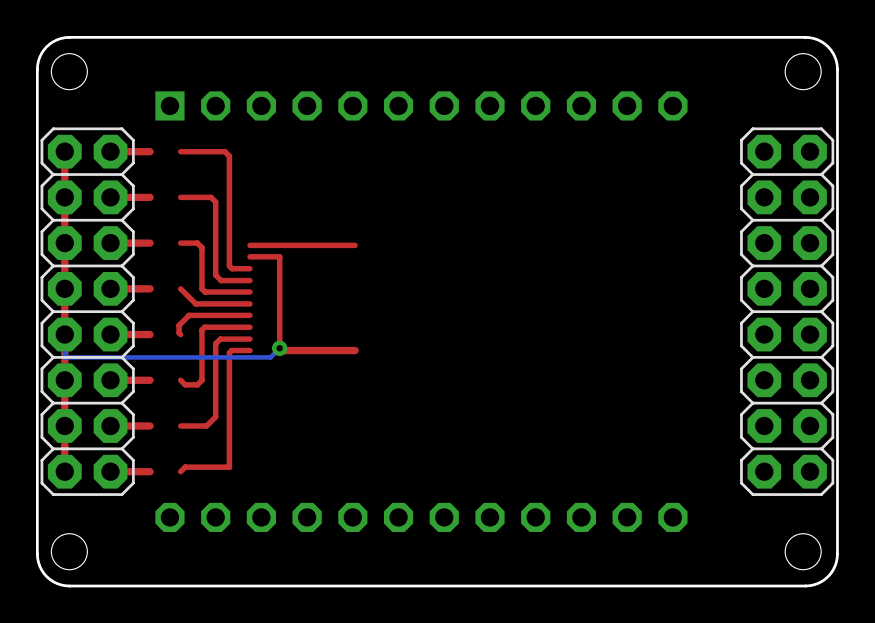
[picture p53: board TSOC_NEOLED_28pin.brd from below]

Board: 2 copper layers, 44.5 x 30.5 mm, 15 parts (2 on the bottom side), 22 nets.

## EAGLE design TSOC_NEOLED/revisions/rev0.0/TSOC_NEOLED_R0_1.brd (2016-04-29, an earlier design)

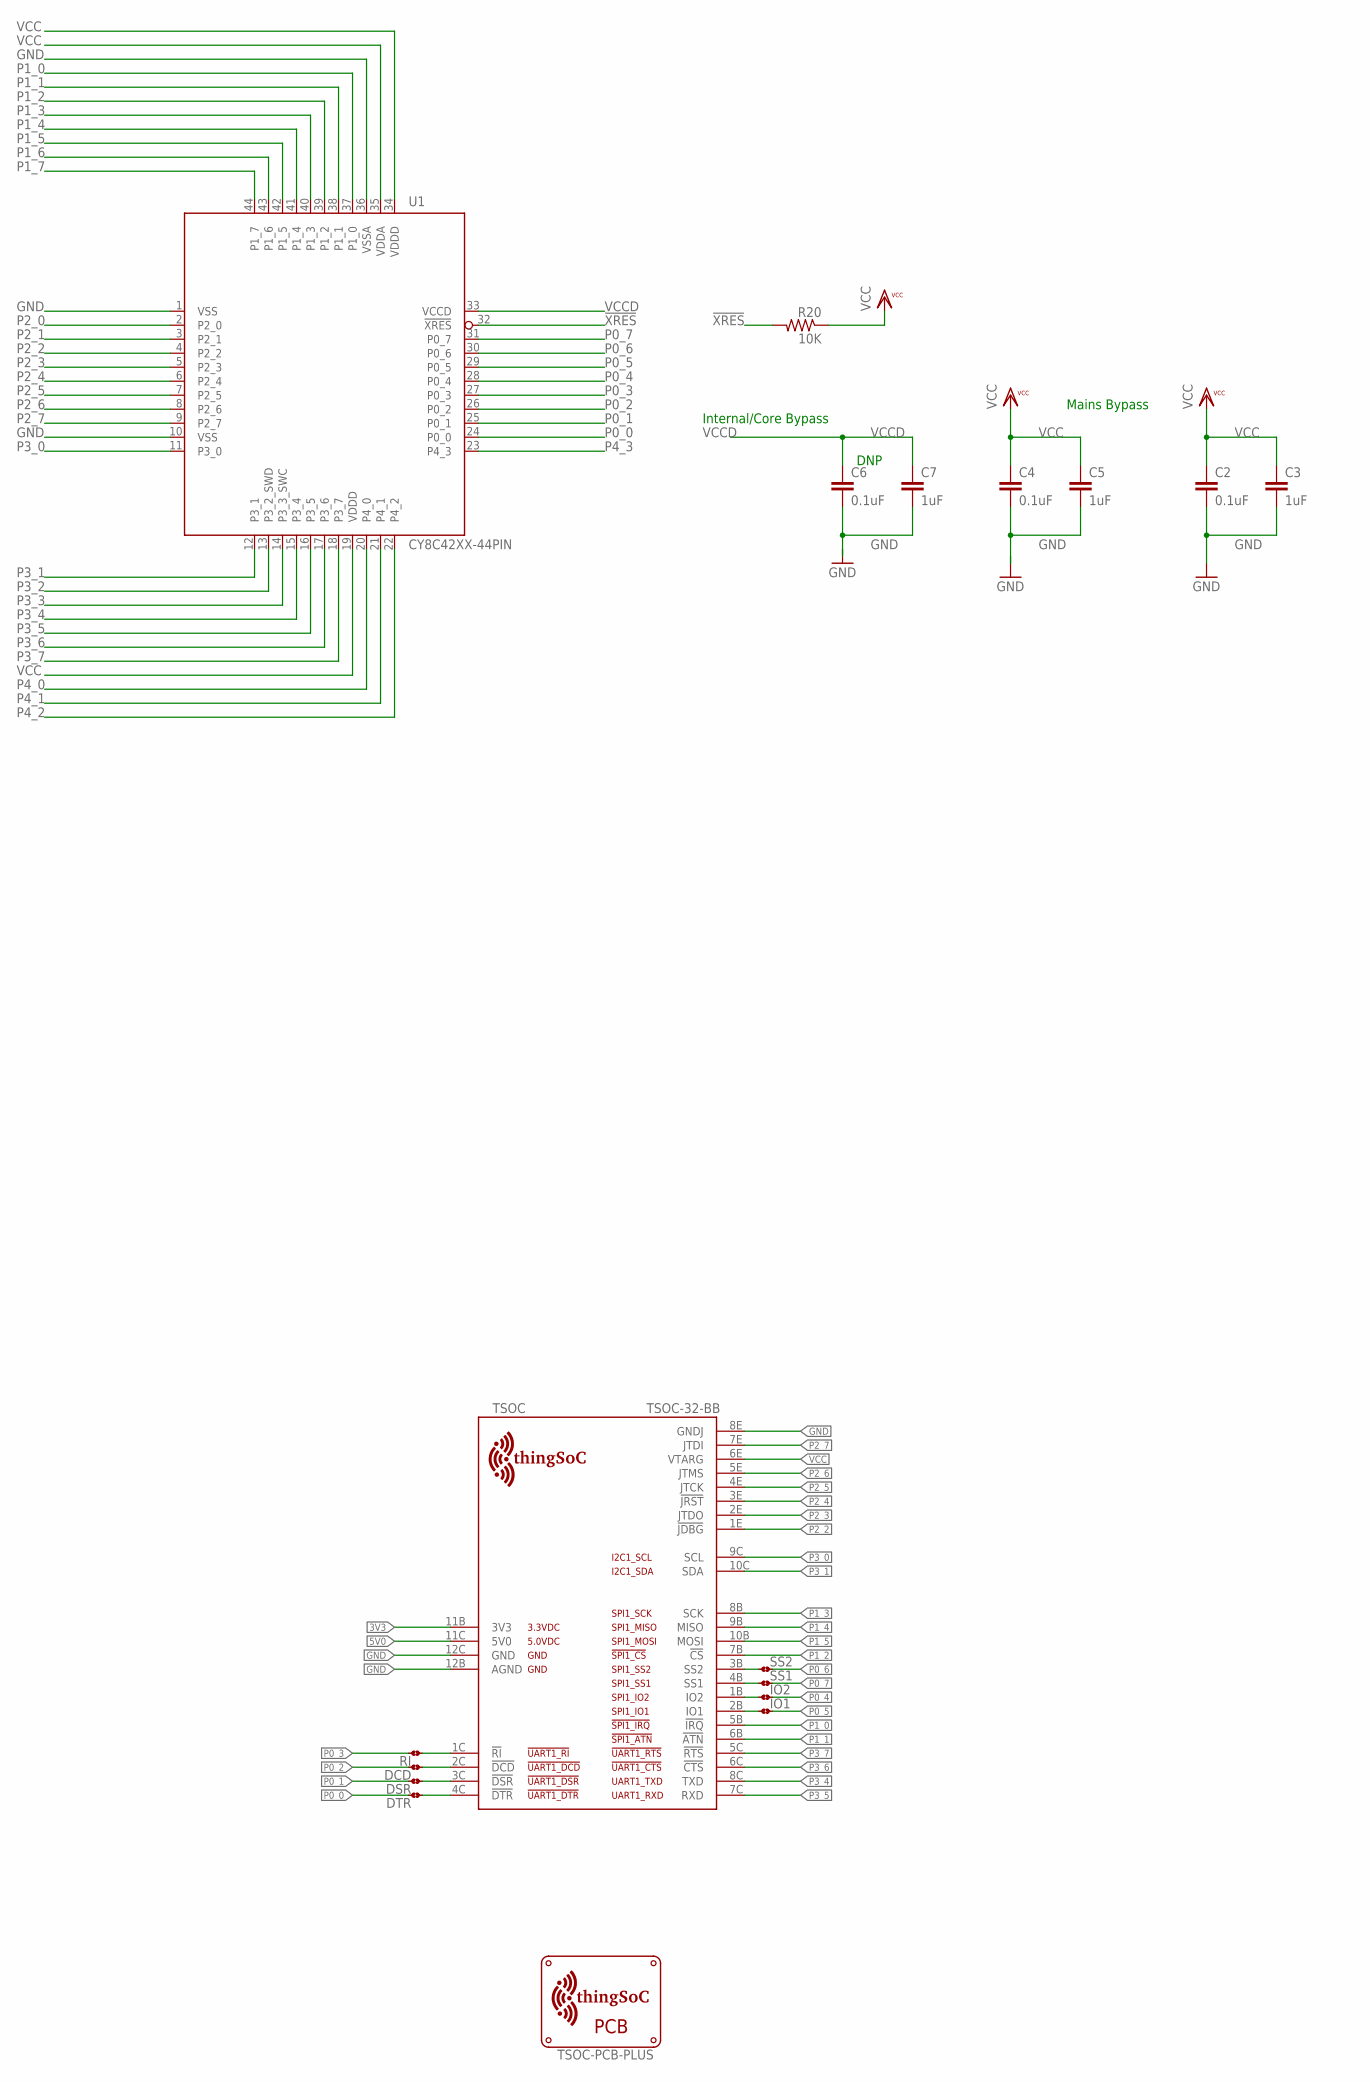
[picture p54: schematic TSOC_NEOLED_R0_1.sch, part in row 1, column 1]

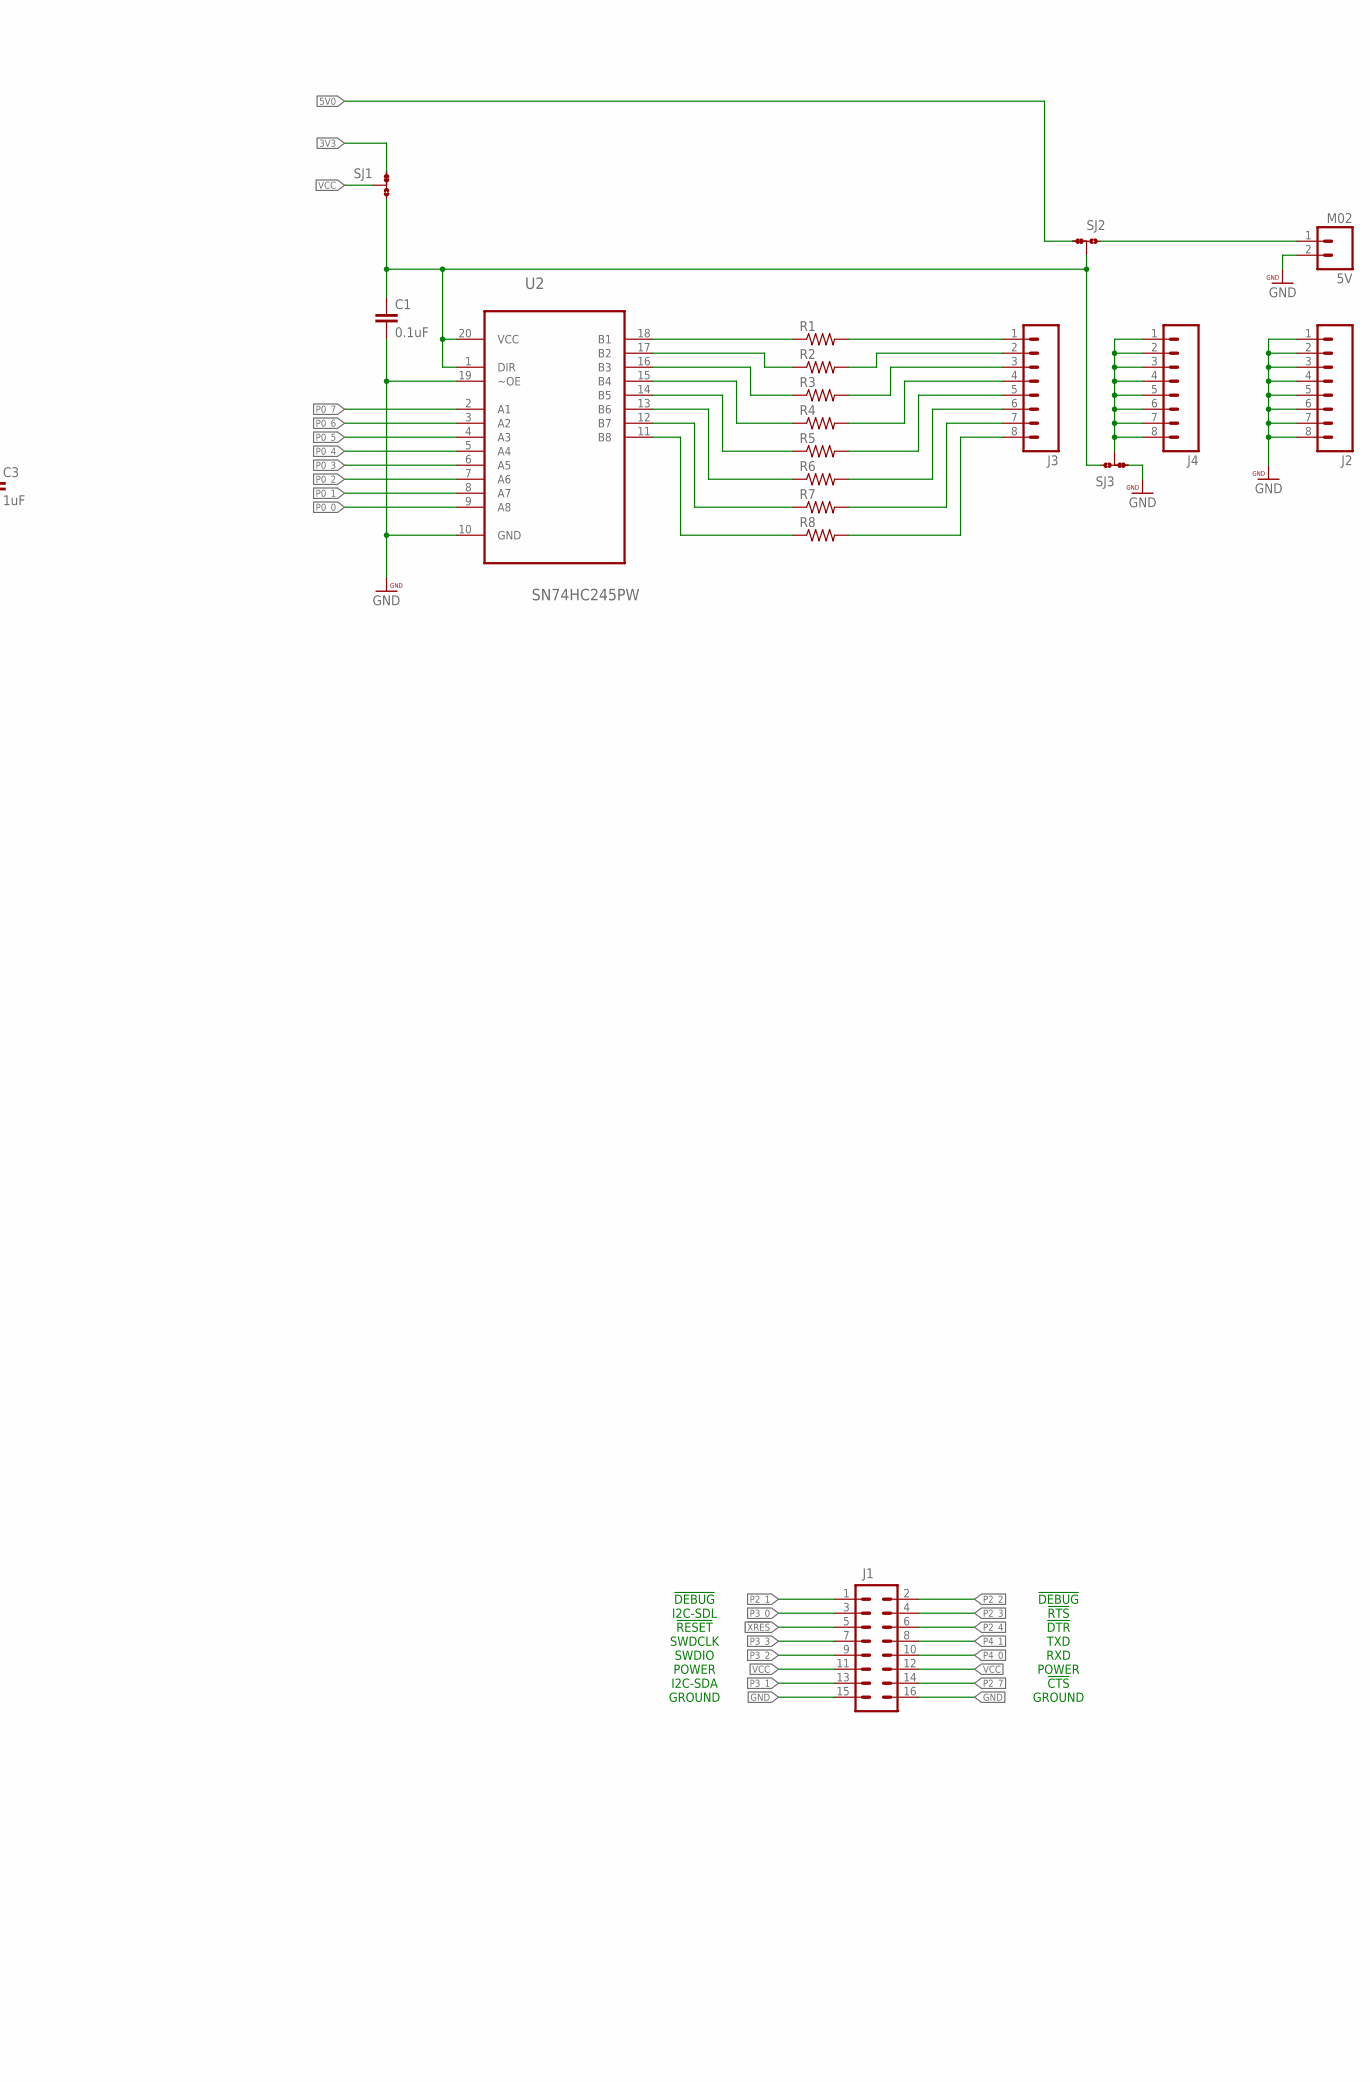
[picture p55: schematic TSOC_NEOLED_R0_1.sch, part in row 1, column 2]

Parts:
5V: M02; 1X02
C1, C2, C4, C6: 0.1uF; 0603-CAP
C3, C5, C7: 1uF; 0603-CAP
DCD: JMP-2-NO
DSR: JMP-2-NO
DTR: JMP-2-NO
IO1, IO2: JMP-2-NO
J1: M08X2; 2X8
J2, J3, J4: M08; 1X08_ROUND
R1, R2, R3, R4, R5, R6, R7, R8: RESISTOR0603-RES; 0603-RES
R20: 10K; 0603-RES
RI: JMP-2-NO
SJ1, SJ2, SJ3: JMP-3-1_2
SS1, SS2: JMP-2-NO
TSOC: TSOC-32-BB; TSOC-BB-S32
U1: CY8C42XX-44PIN; TQFP-10X10-44
U2: SN74HC245PW; SOP65P640X120-20N
U$3: TSOC-PCB-PLUS; TSOC-BB-BRD-PLUS

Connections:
3V3: SJ1.1, TSOC.11B (3V3)
5V0: SJ2.1, TSOC.11C (5V0)
!DCD: DCD.1, TSOC.2C (!DCD)
!DSR: DSR.1, TSOC.3C (!DSR)
!DTR: DTR.1, TSOC.4C (!DTR)
!R!: RI.1, TSOC.1C (!RI)
!XRES: J1.5, R20.2, U1.32 (!XRES)
GND: 5V.2, C1.2, C2.2, C3.2, C4.2, C5.2, C6.2, C7.2, J1.15, J1.16, J2.1, J2.2, J2.3, J2.4, J2.5, J2.6, J2.7, J2.8, SJ3.1, TSOC.8E (GNDJ), TSOC.12B (AGND), TSOC.12C (GND), U1.1 (VSS), U1.10 (VSS), U1.36 (VSSA), U2.10 (GND), U2.19 (~OE)
IO1: IO1.1, TSOC.2B (IO1)
IO2: IO2.1, TSOC.1B (IO2)
unnamed: J3.1, R1.2
unnamed: J3.2, R2.2
unnamed: J3.3, R3.2
unnamed: J3.4, R4.2
unnamed: J3.5, R5.2
unnamed: J3.6, R6.2
unnamed: J3.7, R7.2
unnamed: J3.8, R8.2
unnamed: R1.1, U2.18 (B1)
unnamed: R2.1, U2.17 (B2)
unnamed: R3.1, U2.16 (B3)
unnamed: R4.1, U2.15 (B4)
unnamed: R5.1, U2.14 (B5)
unnamed: R6.1, U2.13 (B6)
unnamed: R7.1, U2.12 (B7)
unnamed: R8.1, U2.11 (B8)
P0_0: DTR.2, U1.24 (P0_0), U2.9 (A8)
P0_1: DSR.2, U1.25 (P0_1), U2.8 (A7)
P0_2: DCD.2, U1.26 (P0_2), U2.7 (A6)
P0_3: RI.2, U1.27 (P0_3), U2.6 (A5)
P0_4: IO2.2, U1.28 (P0_4), U2.5 (A4)
P0_5: IO1.2, U1.29 (P0_5), U2.4 (A3)
P0_6: SS2.2, U1.30 (P0_6), U2.3 (A2)
P0_7: SS1.2, U1.31 (P0_7), U2.2 (A1)
P1_0: TSOC.5B (!IRQ), U1.37 (P1_0)
P1_1: TSOC.6B (!ATN), U1.38 (P1_1)
P1_2: TSOC.7B (!CS), U1.39 (P1_2)
P1_3: TSOC.8B (SCK), U1.40 (P1_3)
P1_4: TSOC.9B (MISO), U1.41 (P1_4)
P1_5: TSOC.10B (MOSI), U1.42 (P1_5)
P1_6: U1.43 (P1_6)
P1_7: U1.44 (P1_7)
P2_0: U1.2 (P2_0)
P2_1: J1.1, U1.3 (P2_1)
P2_2: J1.2, TSOC.1E (!JDBG), U1.4 (P2_2)
P2_3: J1.4, TSOC.2E (JTDO), U1.5 (P2_3)
P2_4: J1.6, TSOC.3E (!JRST), U1.6 (P2_4)
P2_5: TSOC.4E (JTCK), U1.7 (P2_5)
P2_6: TSOC.5E (JTMS), U1.8 (P2_6)
P2_7: J1.14, TSOC.7E (JTDI), U1.9 (P2_7)
P3_0: J1.3, TSOC.9C (SCL), U1.11 (P3_0)
P3_1: J1.13, TSOC.10C (SDA), U1.12 (P3_1)
P3_2: J1.9, U1.13 (P3_2_SWD)
P3_3: J1.7, U1.14 (P3_3_SWC)
P3_4: TSOC.8C (TXD), U1.15 (P3_4)
P3_5: TSOC.7C (RXD), U1.16 (P3_5)
P3_6: TSOC.6C (!CTS), U1.17 (P3_6)
P3_7: TSOC.5C (!RTS), U1.18 (P3_7)
P4_0: J1.10, U1.20 (P4_0)
P4_1: J1.8, U1.21 (P4_1)
P4_2: U1.22 (P4_2)
P4_3: U1.23 (P4_3)
SS1: SS1.1, TSOC.4B (SS1)
SS2: SS2.1, TSOC.3B (SS2)
VCC: C2.1, C3.1, C4.1, C5.1, J1.11, J1.12, R20.1, SJ1.2, TSOC.6E (VTARG), U1.19 (VDDD), U1.34 (VDDD), U1.35 (VDDA)
VCCD: C6.1, C7.1, U1.33 (VCCD)
VEXT: 5V.1, SJ2.3
VIN: C1.1, SJ1.3, SJ2.2, SJ3.3, U2.1 (DIR), U2.20 (VCC)
VOUT: J4.1, J4.2, J4.3, J4.4, J4.5, J4.6, J4.7, J4.8, SJ3.2

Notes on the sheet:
DNP
Internal/Core Bypass
Mains Bypass
I2C-SDA
I2C-SDL
!RESET
SWDCLK
SWDIO
POWER
GROUND
!DEBUG
!RTS
!CTS
!DTR
TXD
RXD

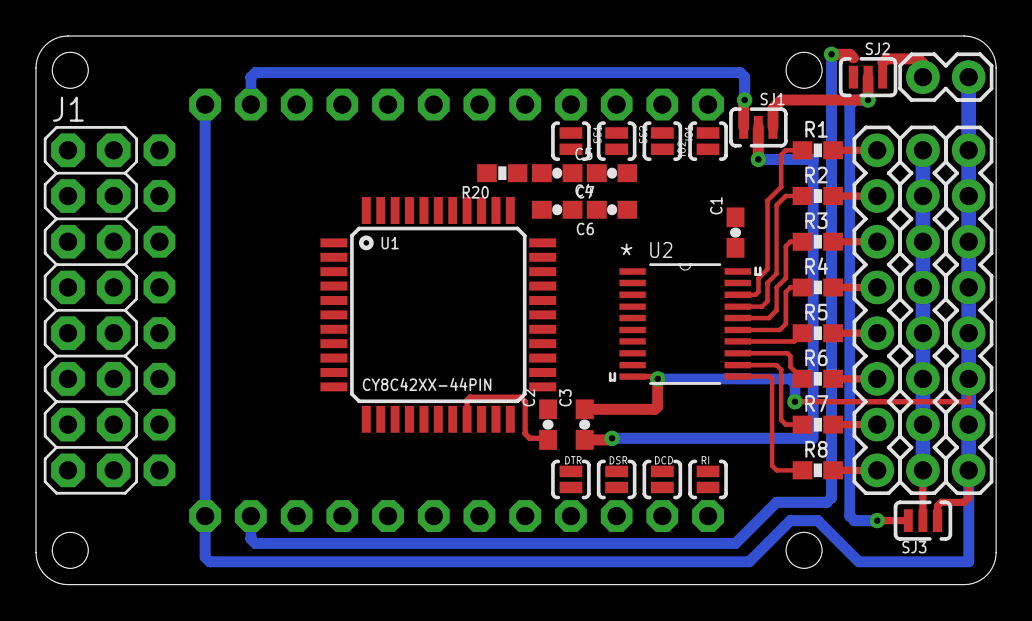
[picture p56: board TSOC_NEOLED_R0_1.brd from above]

Board: 2 copper layers, 53.3 x 30.5 mm, 36 parts (0 on the bottom side), 64 nets.

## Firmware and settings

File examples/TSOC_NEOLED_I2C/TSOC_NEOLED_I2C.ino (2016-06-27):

/*  ------------------------------------------
 *  TSOC_NEOLED I2C (2-Wire) Interface Example
 *  ------------------------------------------
 *  
 *  The TSOC_NEOLED Board is a programmable LED driver
 *  board for strings of WS2812 Color LEDs. The factory
 *  default programming for the TSOC_NEOLED supports up to
 *  eight (8) strings of 64 LEDs per string (512 LEDs total). 
 *  The TSOC-NEOLED allocates eight(8) bits (one byte) each 
 *  for Red, Green, Blue, and also a Yellow/White channel,
 *  for a 32 bit value per LED, or a total of 2048 bytes.
 *  
 *  The color ordering (byte address) is as follows :
 *  0 - LED0 Green
 *  1 - LED0 Red
 *  2 - LED0 Blue
 *  3 - LED0 Yellow
 *  4 - LED1 Green
 *  5 - LED1 Red
 *  6 - LED1 Blue
 *  7 - LED1 Yellow
 *  
 *  The TSOC_NEOLED looks to the Arduino like an I2C SRAM (memory) 
 *  of 2048 bytes in size. Simply writing to the TSOC_NEOLED like an
 *  I2C memory caues the corresponding LED to light up on the display.
 *  
 *  If the LEDs are RGB only type, then the Yellow channel is not used,
 *  however the addressing remains the same, that is to say, memory is 
 *  reserved for the Yellow/White channel, even if it is not used.
 *  
 *  If the LED string (or matrix panel) is less than 64 LEDs (i.e. string of 30 or 60),
 *  then the extra LED positions are not used, however the addressing remains the same, 
 *  that is to say, memory is reserved for 64 LEDs per string, even if it is less than that.
 *  
 *  The Default I2C address for the TSOC_NEOLED is 8 (Seven bits).
 *  
 *  This simple example lights each color of each LED in sequence,
 *  from low addresses to high addresses.
 *  
 */
#include <Wire.h>
#define TSOC_NEOLED_I2CADDRESS         8  // default I2C address
#define TSOC_NEOLED_LED_PER_STRING    64  // default number of LEDs per string
#define TSOC_NEOLED_NUM_STRINGS        1  // set this to the number of strings installed (max=8)
#define TSOC_NEOLED_NUM_COLORS         4  // default is RGBY color space
#define TSOC_NEOLED_LED_ON          0xFF  // LED full brightness
#define TSOC_NEOLED_LED_OFF         0x00  // LED off
#define TSOC_NEOLED_LED_DELAY        100  // Delay to process the I2C write transaction

void setup() {
 Wire.begin();  // Start the Arduino I2C interface
}

byte column, row = 0;
void loop() {
  // Simple test of each LED in order from low address to high address
  for (row=0; row < TSOC_NEOLED_NUM_STRINGS; row++) { 
    for (column=0; column < (TSOC_NEOLED_LED_PER_STRING*TSOC_NEOLED_NUM_COLORS); column++) {  
        // Turn one color of one LED On
        Wire.beginTransmission(TSOC_NEOLED_I2CADDRESS);  // Start the I2C transaction
        Wire.write(row);                                 // Send the high byte of 16 bit memory address
        Wire.write(column);                              // Send the low byte of 16 bit memory address  (ie. the 
        Wire.write(TSOC_NEOLED_LED_ON);                  // Send a single data byte  (we could send more...)
        Wire.endTransmission();                          // End the I2C transaction
        delay(TSOC_NEOLED_LED_DELAY);                    // Delay to process the write cycle
      
        // Turn one color of one LED Off
        Wire.beginTransmission(TSOC_NEOLED_I2CADDRESS);  // Start the I2C transaction
        Wire.write(row);                                 // Send the high byte of address (the string number)
        Wire.write(column);                              // Send the low byte of address (the LED+Color number)
        Wire.write(TSOC_NEOLED_LED_OFF);                 // Send a single data byte  (we could send more...)
        Wire.endTransmission();                          // End the I2C transaction
        delay(TSOC_NEOLED_LED_DELAY);                    // Delay to process the write cycle
    }
  }
}

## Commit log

2016-04-29 update to Rev1.0
    [TSOC_NEOLED.brd, TSOC_NEOLED.sch, TSOC_NEOLED_28pin.brd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]
2016-04-29 update images
    [TSOC_NEOLED.skp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]
2016-04-29 update to Rev1.1
    [TSOC_NEOLED.skp, TSOC_NEOLED_R1_1.brd, TSOC_NEOLED_R1_1.sch]
2016-05-23 update BOM
2016-06-27 update firmware
    [TSOC_NEOLED_R1_2.brd, TSOC_NEOLED_R1_2.sch]
2016-06-27 update gerbers
    [TSOC_NEOLED.skp]
2016-07-21 update descriptions
    [TSOC_NEOLED.brd, TSOC_NEOLED_28pin.brd, TSOC_NEOLED_28pin.sch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]
2016-07-21 update tutorial
    [TSOC_NEOLED_28pin.brd, TSOC_NEOLED_28pin.sch, TSOC_NEOLED_R0_1.brd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]
2016-07-26 update to V2_0
    [TSOC_NEOLED.skp, TSOC_NEOLED_R2_0.brd, TSOC_NEOLED_R2_0.sch]
2016-08-08 add servo example
2017-01-16 update documetation
    [TSOC_NEOLED.skp]
2017-02-28 update docs
    [TSOC_NEOLED.brd, TSOC_NEOLED.sch]

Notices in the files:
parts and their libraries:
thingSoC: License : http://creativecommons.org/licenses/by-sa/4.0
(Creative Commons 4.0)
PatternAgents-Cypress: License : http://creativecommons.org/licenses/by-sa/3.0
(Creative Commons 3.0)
